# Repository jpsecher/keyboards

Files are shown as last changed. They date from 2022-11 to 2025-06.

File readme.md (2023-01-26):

# Custom Keyboard

Goals
- Good ergonomics
- Good for programming
- No drivers
- Configurable
- Use standard components where possible

On the ergonomics side, the initial design will be a pseudo-split staggered-column because it follows the natural physiology of the hands, and because I only need to make one or two for myself.  I want to make a PCB for the keyboard, so it seems to convoluted to go all the way to curved surfaces (eg. wells).  With a PCB, I can also support hot-swappable keys, which makes it possible to try out different spring weights for the individual fingers (like the [Absolem](https://zealot.hu/absolem/)).  And no stabilisers should be needed because the keys should just be where your finger naturally land, and therefore there should be no need for large 2U keys.  For the thumb keys, size 1.5U is probably sufficient.

Keys that need to be hold down while pressing other keys should only be operated by strong fingers.  So all modifier keys and layer shifting should probably be in the thumbs area, where it will be most comfortable to hold down a keys (as opposed to tapping the key).  But some modifier keys need to be hold down together, so these modifiers then need to be on opposite sides, using both thumbs at the same time.  

Good ergonomics with no curvatures then means that the number of keys must be limited to avoid stretching the fingers too much.  Which means that the keyboard needs to have several layers to accommodate all the ASCII characters used in programming, as well as the various European letters I use daily.  I am toying with the idea of using the thumb keys exclusively for layer-shift and control keys.

The keyboard should use standard hot-swappable Cherry MX keys.  And to ease experimentation, I will start out with DSA profile key caps.

## Layers

Contexts:

  1.  Programming (standard languages) in non-modal text editor.
  1.  Documentation (Markdown) in non-modal editor.
  1.  Terminal (shell) operations.
  1.  Window manager navigation.
  1.  Music control (easy identification of Play/Pause key at a glance)

And:

- Function keys are important in many of the applications I use.
- Editors usually inserts ending parenthesis/brace/bracket automatically.
- I don't care about RGB LEDs, as long as I can turn them off.
- I occasionally use Nordic/German/Greek letters when writing text.
- I want modifiers and layer keys on thumbs, and they should stay in the same place as much as possible.

Also, I prefer that each group of keys follow the traditional QWERTY layout, simply because it makes switching between keyboards less stressful.

## Keyboards in this repository

- [Acacia](acacia/): a pseudo-split 40 key column-staggered keyboard

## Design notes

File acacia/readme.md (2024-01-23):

# Acacia keyboard

A custom built mechanical keyboard with just 38 keys plus two extra media keys.

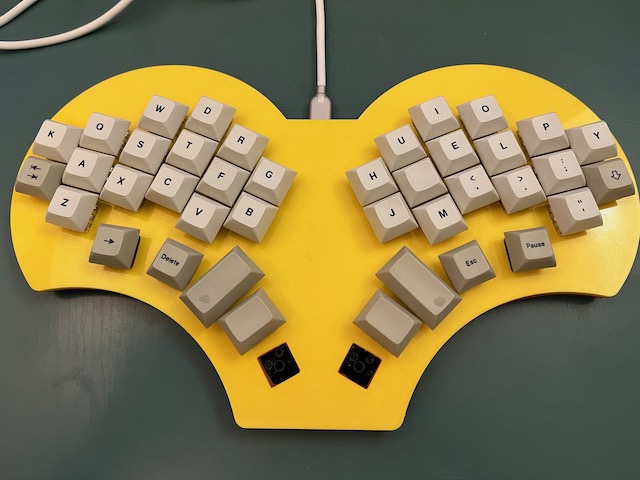
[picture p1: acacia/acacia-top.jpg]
Top side


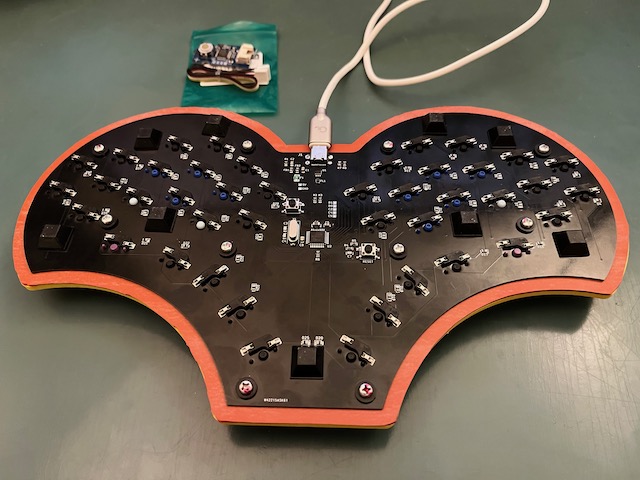
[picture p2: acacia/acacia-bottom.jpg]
PCB side


The [layout](acacia.pdf) uses three layers.  One for alphas, one for navigation/function keys, and one for symbols/numpad.

The thumb home keys double as layer switches and tab/space.  The lower thumb keys are one-shot shift keys.

The Escape key is a [Layer Lock](https://getreuer.info/posts/keyboards/layer-lock) on both upper layers, which eliminates the strain of holding down the thumb for prolonged navigation and number punching.  And it makes it possible to move one hand to a trackball while using the other hand for mouse buttons.

The lower home row (Z, X, C, V) doubles as modifiers (AltGr, GUI, Alt, Control), and these functions are mirrored on the other hand (M, comma, period, quote).  This mirroring of modifiers is carried through on both other layers.

If used on macOS, then the Control and GUI (Command) keys should be swapped at the OS level.

As seen on the picture, the current layout for the alphas is [Minimak-6](http://www.minimak.org/), and it works very well with the already relocated T and Y keys on Acacia.  It is pretty close to standard QWERTY, so changing between the two should not be a problem.

## Improvements

- Remove the now unused lower thumb keys.
- Adjust the thumb keys slightly to make sure that key caps of any reasonable size do not collide.  Also, the thumb home key could be a little less tilted, and the whole bock moved a little further towards the middle.
- Align Q and P keys with ring finger use (instead of pinky use), or simply tilt the pinky columns the same as the ring finger column.
- Include a trackball (as alluded to in the pictures).  Unfortunately the ATmega32U2 used in the build does not have built-in I2C communication, so unless the controller is upgraded to eg. ATmega32U4, the communication has to be done brute-force through some of the five unused GPIO pins.
- Make a proper (wooden?) case.
- Shielding for the PCB.
- Layer status output, eg. through LEDs.

## Alternatives

- After finishing the prototypes, I discovered this repo: https://github.com/AlaaSaadAbdo/battoota/

## Version 2

The TM040040 trackpad needs the R1 (470k) resistor removed to use I2C and the R7 (0?) & R8 (0?) resistors removed for 5V.  The flex cable needed is 05-12-D-0050-A or another cable with contacts on oposite sides.

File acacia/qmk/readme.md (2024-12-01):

# Acacia

A pseudo-split keyboard with 2+4x3+2 vertically staggered keys and 4+1 thumb keys for each hand.

* Keyboard Maintainer: [jpsecher](https://github.com/jpsecher)
* Hardware Supported: https://github.com/jpsecher/keyboards/acacia

Make example for this keyboard (after setting up your build environment):

    make handwired/acacia:default

Flashing example for this keyboard:

    make handwired/acacia:default:flash

See the [build environment setup](https://docs.qmk.fm/#/getting_started_build_tools) and the [make instructions](https://docs.qmk.fm/#/getting_started_make_guide) for more information.  If the chip is completely blank, then you might have to forcefully erase it like

    dfu-programmer atmega32u2 erase --force

## Acacia-2

    make handwired/acacia_2:qwerty-36-pc
    make handwired/acacia_2:qwerty-36-pc:flash

## Bootloader

Enter the bootloader by using the small buttons on the PCB: press the RESET button while connected to QMK Toolbox.

Then you can flash the HEX file you built above.

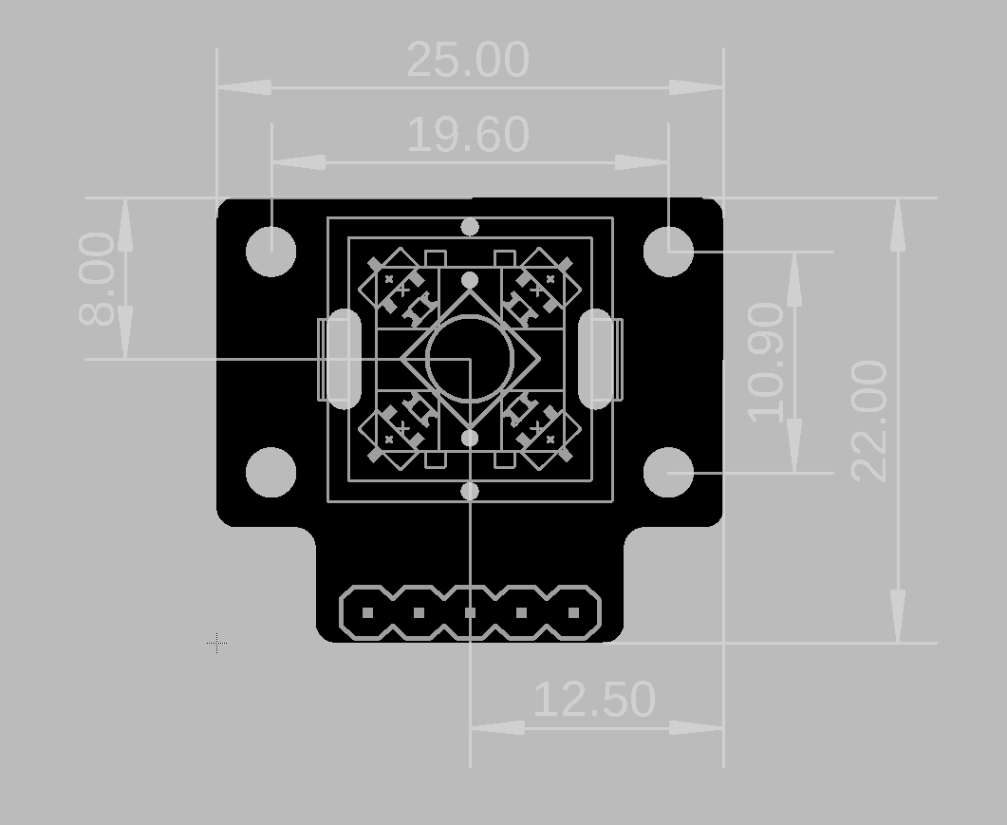
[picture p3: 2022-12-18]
doc/trackballbreakout.png

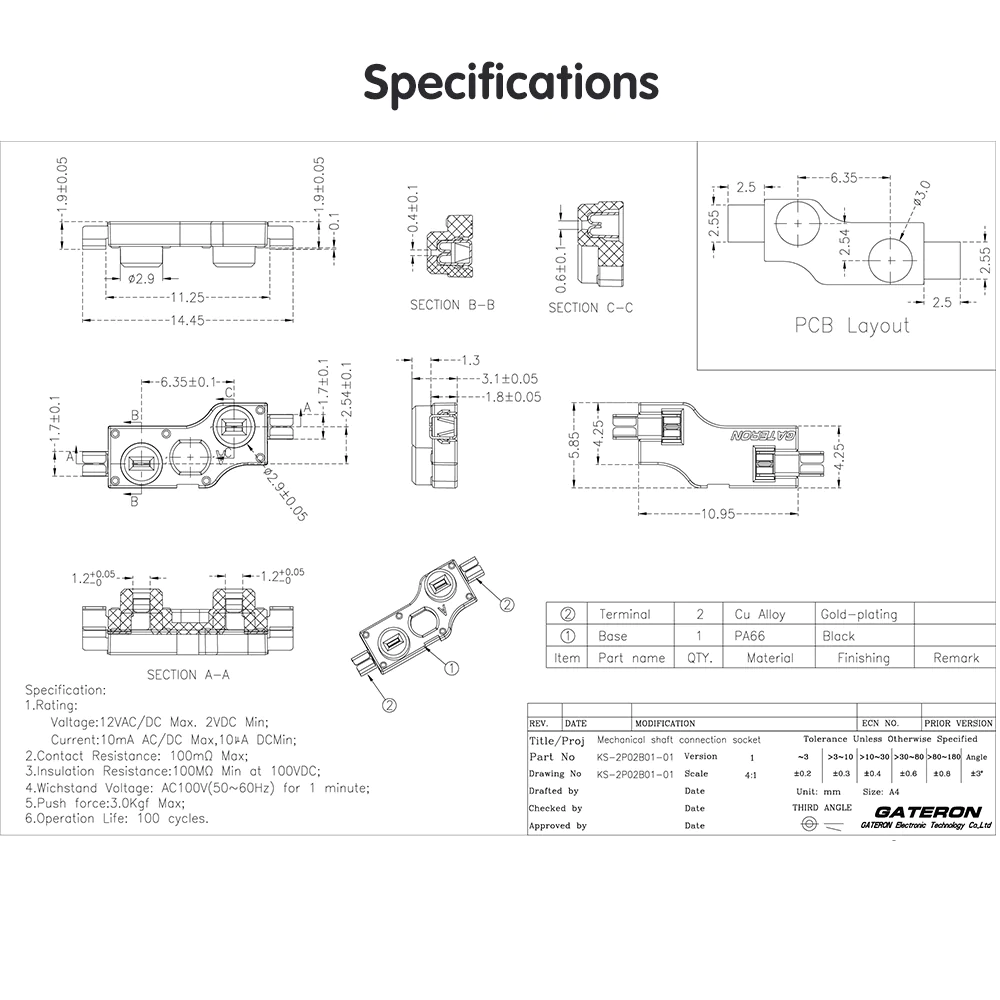
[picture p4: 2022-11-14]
doc/gateron.webp

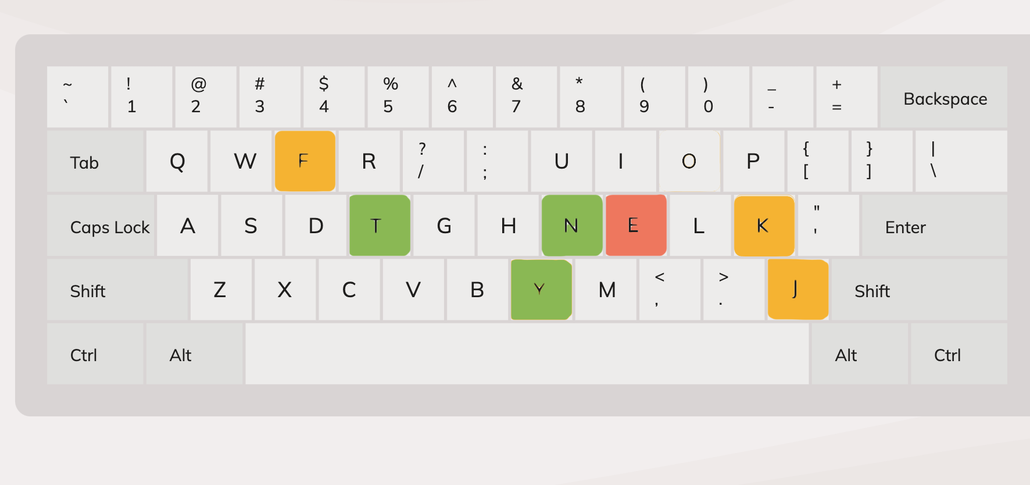
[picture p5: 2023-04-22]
acacia/acacia-diff-querty.png

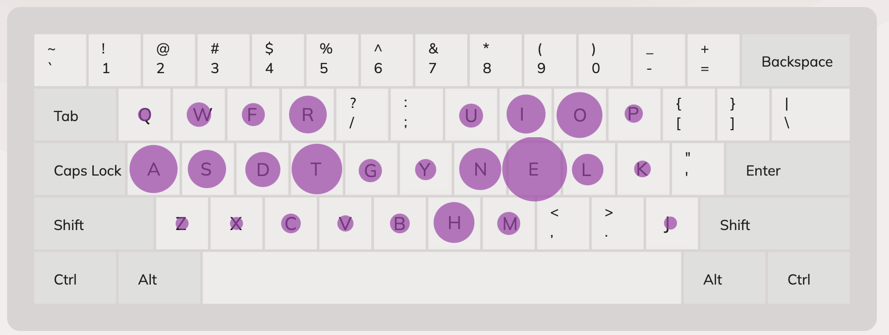
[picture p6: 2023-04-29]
acacia/acacia-on-us-keyboard.png

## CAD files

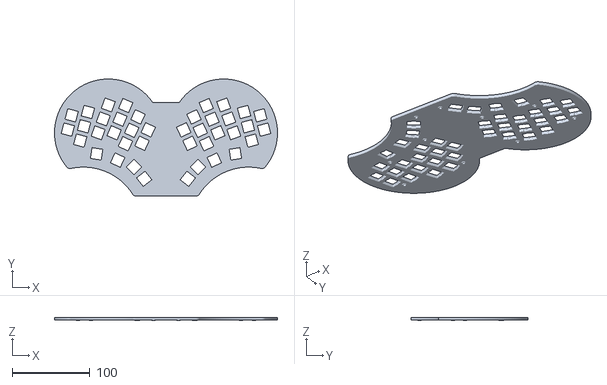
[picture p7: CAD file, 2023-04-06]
acacia/acacia.stl
286.0 x 150.0 x 4.40

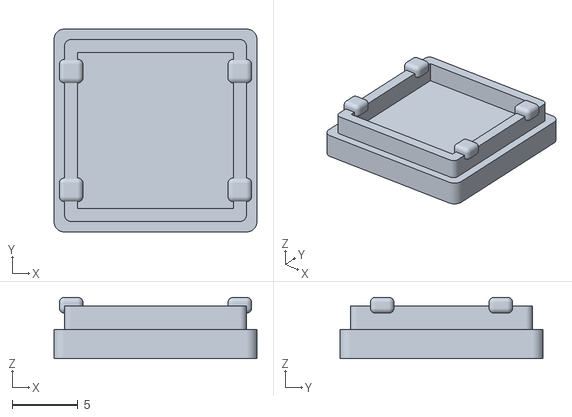
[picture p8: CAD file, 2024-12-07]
covers/choc-v1-cover.stl
15.4 x 15.4 x 4.65

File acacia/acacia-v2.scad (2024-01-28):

// Acacia V2
//
// A Mechanical Keyboard

$fn = 128;

// All constants are in mm
height = 4.6;
feet_height = 8;
wall = 4;
pcb_height = 1.2;
mountin_hole = 3;
membrane = 1;
key_distance = 19;
key_hole = 14;
key_tab_indent = 0.5;
key_tab_width = 5.0;
key_tab_submersion = 1.3;

module mirror2(vector) {
  children();
  mirror(vector) children();
}

module keyholder () {
  margin = 0.5;
  h = height+(2*margin);
  translate([0,0,-0.5]) {
    union() {
      // hole
      linear_extrude(h) {
        square(key_hole, center=true);
      }
      // botton indent for lock
      linear_extrude(h-margin-key_tab_submersion) {
        mirror2([0,1,0]) {
          translate([0,-(key_hole+key_tab_indent)/2,0]) {
            square([key_tab_width,key_tab_indent], center=true);
          }
        }
      }
    }
  }
}

module key (units) {
  union() {
    keyholder();
    // Outline of keycap, hidden by default
    *translate([0,0,height-1]) {
      linear_extrude(2) {
        square([key_distance*units-1,key_distance-1], center=true);
      }
    }
  }
}

module array (count, distance) {
  for (i=[0:1:count-1]) {
    translate([0,distance*i,0])
      children();
  }
}

module turn (degree) {
  rotate([0,0,degree])
    children();
}

module two_keys () {
  array(2, key_distance)
    key(1);
}

module three_keys () {
  array(3, key_distance)
    key(1);
}

module four_keys () {
  three_keys();
  translate([key_distance,key_distance,0]) turn(90) key(1.5);
}

module five_keys () {
  three_keys();
  translate([key_distance,key_distance/2,0]) two_keys();
}

module index_finger_full () {
  turn(15) mirror([1,0,0]) five_keys();
}

module middle_finger () {
  turn(15) three_keys();
}

module ring_finger () {
  turn(15) three_keys();
}

module pinky_full () {
  turn(15) four_keys();
}

module thumbs () {
  translate([71.7,80]) turn(-75) key(1.5);
  translate([50,68]) turn(15) key(1);
  translate([31.5,63]) turn(-75) key(1.5);
  translate([13,58]) turn(-75) key(1);
}

module right_hand () {
  translate([49,89,0]) index_finger_full();
  translate([65.5,103,0]) middle_finger();
  translate([86.5,99,0]) ring_finger();
  translate([108,93,0]) pinky_full();
  thumbs();
}

module plate_2d () {
  minkowski() {
    difference() {
      union() {
        translate([8,46,0]) square([100,82]);
        translate([82,104]) circle(50);
      }
      translate([98,-33,0]) circle(100);
    }
    circle(7);
  }
}

module interior_2d () {
  offset(-wall) plate_2d();
}

module interior_3d () {
  translate([0,0,-0.5]) {
    linear_extrude(feet_height+0.5) {
      interior_2d();
    }
  }
}

module plate_3d () {
  difference() {
    linear_extrude(height+feet_height) {
      plate_2d();
    }
    interior_3d();
  }
}

module right_side () {
  difference() {
    plate_3d();
    translate([3,-3,feet_height]) right_hand();
  }
}

module left_side () {
  mirror([1,0,0]) right_side();
}

// Complete 2D area without holes
module complete_2d () {
  difference () {
    union () {
      mirror2([1,0,0]) plate_2d();
      translate([0,87,0]) square([35,96], center=true);
    }
    *translate([0,133,0]) square([38,10], center=true);
    *translate([-18,150,0]) circle(22);
    *translate([18,150,0]) circle(22);
  }
}

*complete_2d();

module standoff () {
  difference() {
    translate([0,0,pcb_height]) {
      linear_extrude(membrane) circle(mountin_hole / 2 + 1);
    }
    translate([0,0,-1]) {
      linear_extrude(pcb_height + membrane + 2) 
        circle(mountin_hole / 2 - 0.1);
    }
  }
}

module standoffs_placement () {
  mirror2([1,0,0]) {
    translate([36,49,0]) children();
    translate([93,84,0]) children();
    translate([115,125,0]) children();
    translate([70,143,0]) children();
    translate([24,122,0]) children();
  }
}

module standoffs () {
  standoffs_placement() {
    standoff();
  }
}

module complete_interior_3d () {
  translate([0,0,-0.5]) {
    difference() {
      linear_extrude(feet_height+0.5+membrane) {
        offset(-wall) complete_2d();
      }
      translate([0,0,feet_height-0.5]) standoffs();
    }
  }
}

module complete_keyboard_3d () {
  difference() {
    linear_extrude(height+feet_height) {
      complete_2d();
    }
    complete_interior_3d();
  }
}

module keyboard () {
  difference () {
    complete_keyboard_3d();
    mirror2([1,0,0]) {
      translate([3,-3,feet_height]) right_hand();
    }
  }
}

*keyboard();

module holes () {
  standoffs_placement() {
    translate([0,0,-1]) {
      linear_extrude(height + membrane - 1) 
        circle(mountin_hole / 2 - 0.1);
    }    
  }
}

module plate () {
  difference() {
    union() {
      translate([0,0,membrane])
      difference() {
        linear_extrude(height-membrane) {
          complete_2d();
        }
        // cut out for flat cable
        translate([0,0,-1]) {
          linear_extrude(height-membrane + 2) {
            translate([0,65,0]) square([12,8], center=true);
          }
        }
        // cut out for USB plug
        translate([0,0,-2]) {
          linear_extrude(height-membrane) {
            translate([0,135,0]) square([15,10], center=true);
          }
        }
      }  
      translate([0,0,-membrane]) standoffs();
    }
    holes();
    mirror2([1,0,0]) {
      translate([3,-3,0]) right_hand();
    }
  }
}

// top plate for 3D printing
plate();

// trackpad
*translate([0,85,0]) circle(20);


module pcb () {
  linear_extrude(pcb_height) {
    difference() {
      offset(-wall-1) complete_2d();
      projection(cut=true) holes();
    }
  }
}

// guide for placing the switches & holes on the pcb
*projection() difference() {
  pcb();
  mirror2([1,0,0]) {
    translate([3,-3,-key_tab_submersion/2]) right_hand();
  }
}

// pcb outline
*projection() {
  linear_extrude(pcb_height) {
    offset(-wall-1) complete_2d();
  }
}

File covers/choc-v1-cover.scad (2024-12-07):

// Choc V2 Switch Hole Cover
// All measurements in millimeters
$fn = 128;

// Main Parameters
plate_thickness = 1.2;  // Thickness of the cover plate
plate_overhang = 2;
// tolerance = 0.2;    // Tolerance for better fit

switch_width = 13.8;  // Width of the switch cutout
lip_height = 0.4;
lip_width = 1;
lip_length = 10;

plate_width = switch_width + plate_overhang;

module lid_raw() {
    minkowski() {
        cube([switch_width, switch_width, plate_thickness]);
        cylinder(r=0.8,center=true);
    }
}
*lid_raw();

module lid() {
    translate([-switch_width / 2, -switch_width / 2, 0])
        lid_raw();
}

module rim_raw() {
    difference() {
        minkowski() {
            cube([switch_width - 1, switch_width - 1, 2]);
            cylinder(r=0.5,center=true);
        }
        translate([2*lip_width/2-0.5, 2*lip_width/2-0.5, 0])
            cube([switch_width - 2*lip_width, switch_width - 2*lip_width, 3]);
    }
}
*rim_raw();

module rim() {
    translate([-switch_width / 2 + 0.5, -switch_width / 2 + 0.5, 1])
        rim_raw();
}

module tap_raw() {
    union() {
        translate([0, 0, 1.65+0.5])
            minkowski() {
                cube([lip_width, lip_width, lip_height]);
                sphere(r=0.4);
            }
        translate([0, lip_length - lip_width, 1.65+0.5])
            minkowski() {
                cube([lip_width, lip_width, lip_height]);
                sphere(r=0.4);
            }
    }
}

module tap() {
    translate([-lip_width / 2, -lip_width / 2, plate_thickness])
        tap_raw();
}

module taps() {
    translate([(switch_width - lip_width)/2,-((lip_length-lip_width)/2),0])
        tap();
}

module switch_cover() {
    difference() {
        union() {
            lid();
            rim();
            taps();
            rotate([180,180,0]) taps();
        }
    }
}

switch_cover();

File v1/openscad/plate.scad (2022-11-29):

// The Pork Chop
//
// A Mechanical Keyboard

$fn = 128;

height = 5;
feet_height = 8;

key_distance = 19;

key_hole = 14;
key_tab_indent = 0.5;
key_tab_width = 5.0;
key_tab_submersion = 1.3;

module mirror2(vector) {
  children();
  mirror(vector) children();
}

module keyholder () {
  margin = 0.5;
  h = height+(2*margin);
  translate([0,0,-0.5]) {
    union() {
      // hole
      linear_extrude(h) {
        square(key_hole, center=true);
      }
      // botton indent
      linear_extrude(h-margin-key_tab_submersion) {
        mirror2([0,1,0]) {
          translate([0,-(key_hole+key_tab_indent)/2,0]) {
            square([key_tab_width,key_tab_indent], center=true);
          }
        }
      }
      // top indent
      *translate([0,0,margin+key_tab_submersion]) {
        linear_extrude(h-margin-key_tab_submersion) {
          mirror2([1,0,0]) {
            translate([-(key_hole+key_tab_indent)/2,0,0]) {
              square([key_tab_indent,key_tab_width], center=true);
            }
          }
        }
      }
    }
  }
}

module array (count, distance) {
  for (i=[0:1:count-1]) {
    translate([0,distance*i,0])
      children();
  }
}

module two_keys () {
  array(2, key_distance)
    keyholder();
}

module three_keys () {
  array(3, key_distance)
    keyholder();
}

module turn (degree) {
  rotate([0,0,degree])
    children();
}

module index_finger () {
  turn(25) three_keys();
}

module index_finger_extra () {
  turn(25) two_keys();
}

module middle_finger () {
  turn(23) three_keys();
}

module ring_finger () {
  turn(20) three_keys();
}

module pinkie () {
  turn(15) three_keys();
}

module pinkie_extra () {
  turn(15) two_keys();
}

module thumbs () {
  translate([59,69]) turn(38) keyholder();
  translate([41,55]) turn(55) keyholder();
  translate([30,33]) turn(70) keyholder();
  translate([26,8]) turn(85) keyholder();
}

module right_hand () {
  translate([28,89,0]) index_finger_extra();
  translate([49,90,0]) index_finger();
  translate([64,104,0]) middle_finger();
  translate([84,104,0]) ring_finger();
  translate([107,94,0]) pinkie();
  translate([123,109,0]) pinkie_extra();
  thumbs();
}

module plate_2d () {
  minkowski() {
    difference() {
      union() {
        translate([5,5,0]) square([120,105]);
        translate([72,107]) circle(67);
      }
      translate([140,0,0]) circle(90);
    }
    circle(5);
  }
}

module interior_2d () {
  offset(-5) plate_2d();
}

module interior_3d () {
  translate([0,0,-0.5]) {
    linear_extrude(feet_height+0.5) {
      interior_2d();
    }
  }
}

module plate_3d () {
  difference() {
    linear_extrude(height+feet_height) {
      plate_2d();
    }
    interior_3d();
  }
}

module right_side () {
  difference() {
    plate_3d();
    translate([0,7,feet_height]) right_hand();
  }
}

*right_side();

module left_side () {
  mirror([1,0,0]) right_side();
}

left_side();

module complete_2d () {
  mirror2([1,0,0]) plate_2d();
    difference () {
      translate([0,115,0]) square([15,40], center=true);
      translate([0,137,0]) circle(7);
    }
    translate([-5,0,0]) square(10);
}

module complete_interior_3d () {
  translate([0,0,-0.5]) {
    linear_extrude(feet_height+0.5) {
      offset(-5) complete_2d();
    }
  }
}

module complete_plate_3d () {
  difference() {
    linear_extrude(height+feet_height) {
      complete_2d();
    }
    complete_interior_3d();
  }
}

*difference () {
  complete_plate_3d();
  mirror2([1,0,0]) translate([-1,8,feet_height]) right_hand();
}

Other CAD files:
thrice/thrice.scad
acacia/acacia.scad

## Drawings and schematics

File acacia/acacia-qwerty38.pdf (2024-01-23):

## Keyboard handwired/acacia

## Layout LAYOUT

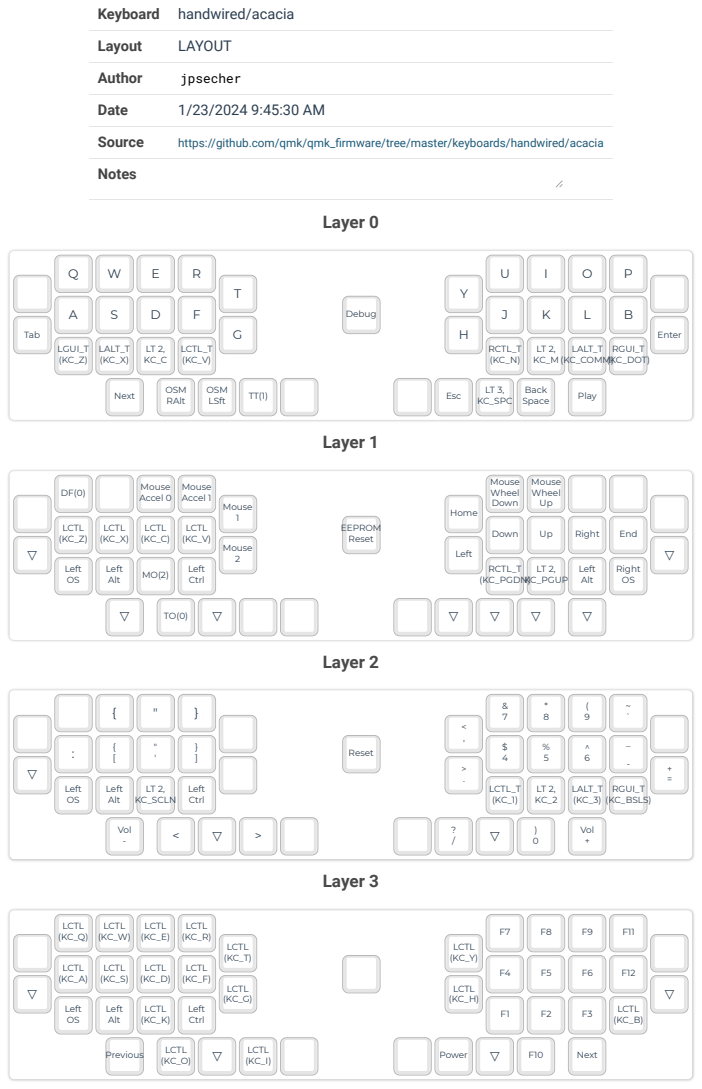
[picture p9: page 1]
Author; jpsecher; Date; Source; https://github.com/qmk/qmk_firmware/tree/master/keyboards/handwired/acacia; Notes; Layer 0; Layer 1; Layer 2; Layer 3; Tab; Enter; LGUI_T (KC_Z); LALT_T (KC_X); LCTL_T (KC_V); RCTL_T (KC_N); LALT_T (KC_COMM); RGUI_T (KC_DOT); Next; OSM; RAlt; OSM LSft; Esc; LT 3, KC_SPC; Back Space; Play; Debug; Mouse; Accel 0; Mouse Accel 1; Mouse 1; Home; Mouse Wheel; Down; LCTL (KC_Z); LCTL (KC_X); LCTL (KC_C); LCTL (KC_V); Mouse 2; Left; Right; End; Left OS; Alt; Left Ctrl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

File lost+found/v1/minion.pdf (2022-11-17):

## Keyboard handwired/pteron

## Layout LAYOUT

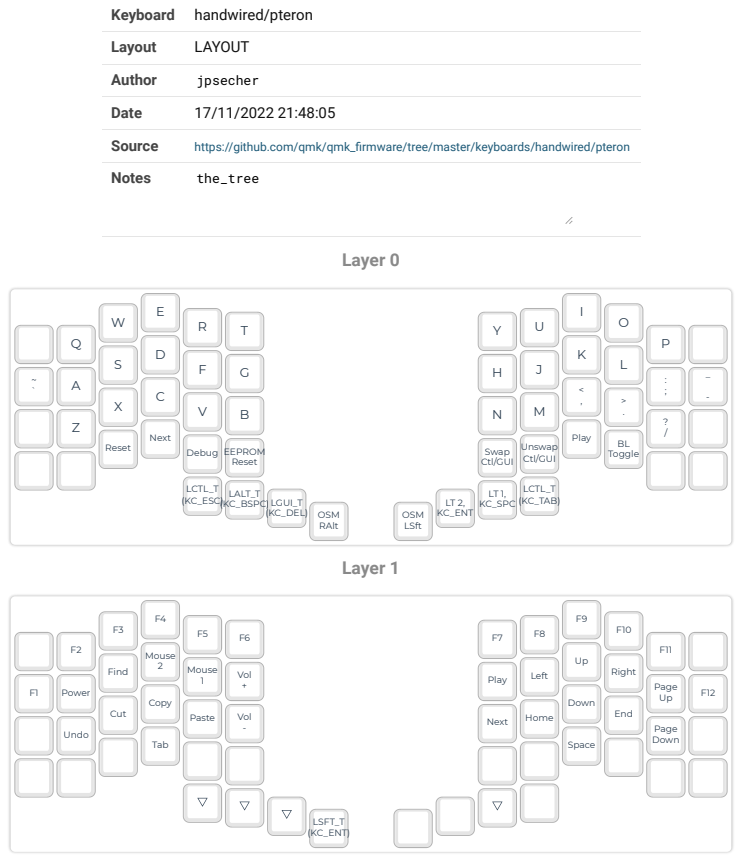
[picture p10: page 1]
Author; jpsecher; Date; Source; https://github.com/qmk/qmk_firmware/tree/master/keyboards/handwired/pteron; Notes; the_tree; Layer 0; Layer 1; Reset; Next; Debug; EEPROM; Swap Ctl/GUI; Unswap Ctl/GUI; Play; Toggle; LCTL_T (KC_ESC); LALT_T (KC_BSPC) LGUI_T; (KC_DEL); OSM; RAlt; OSM LSft; LT 2, KC_ENT; LT 1, KC_SPC; LCTL_T (KC_TAB); Power; Find; Mouse; Vol +; Left; Right; Page Up; Undo; Cut; Copy; Paste; Vol; Home; Down; End; Page Down; Tab; Space; LSFT_T; (KC_ENT)

L

a

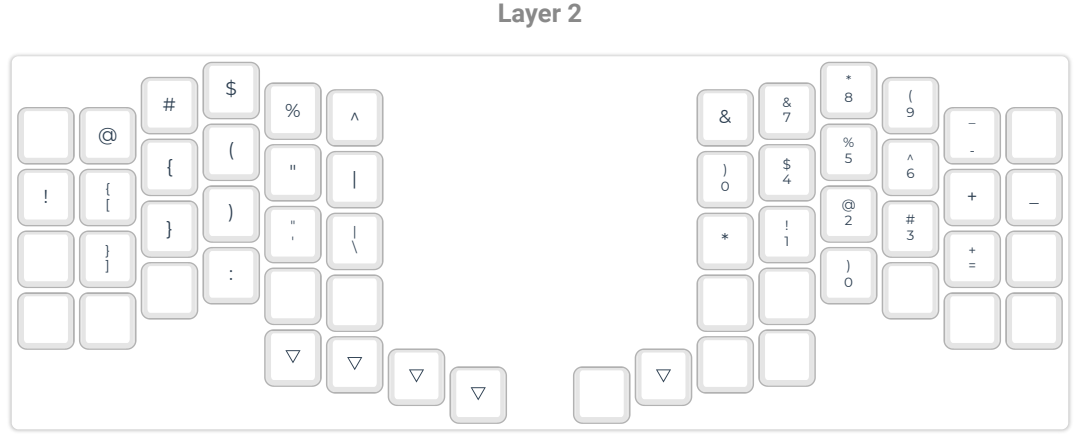
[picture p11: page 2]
yer

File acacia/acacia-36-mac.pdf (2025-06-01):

# Layer 0

Q | W | E | R

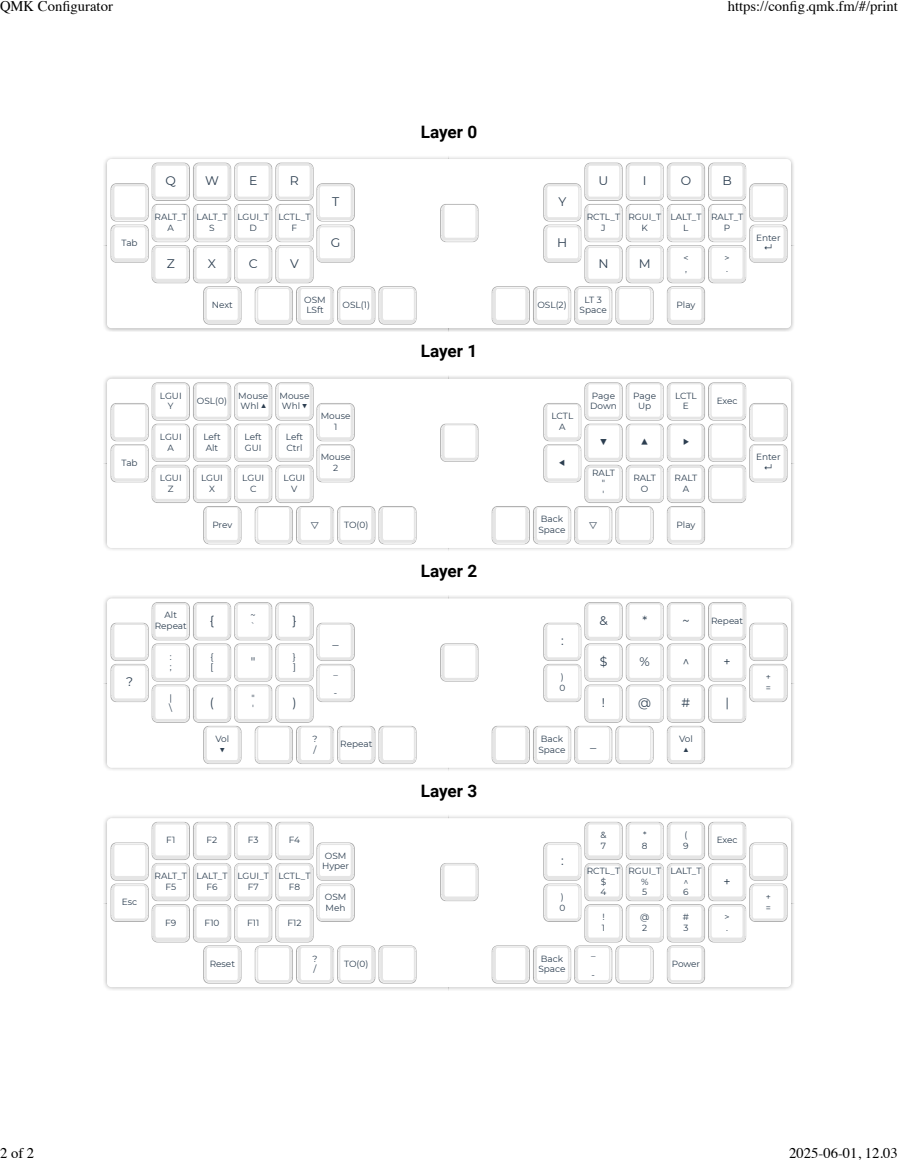
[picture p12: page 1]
Layer 1; Layer 2; Layer 3; Tab; RALT_T A; LALT_T S; LGUI_T D; LCTL_T F; RCTL_T J; RGUI_T K; LALT_T L; RALT_T P; Enter ↵; Next; OSM; LSft; OSL(1); OSL(2); Space; Play; LGUI; OSL(0); Mouse; Whl ⏶; Mouse Whl ⏷; Mouse 1; LCTL A; Page Down; Page Up; LCTL; Exec; LGUI A; Left Alt; Left GUI; Left Ctrl; LGUI Z; LGUI X; LGUI C; LGUI V; RALT " '; RALT O; RALT A; Prev; Back; Alt; Repeat; Vol ⏷; Vol; Hyper; Esc; RALT_T F5; LALT_T F6; LGUI_T F7; LCTL_T F8; OSM Meh; RCTL_T $ 4; RGUI_T % 5; LALT_T ^ 6; Reset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

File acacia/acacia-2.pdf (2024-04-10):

## Keyboard handwired/acacia

## Layout LAYOUT

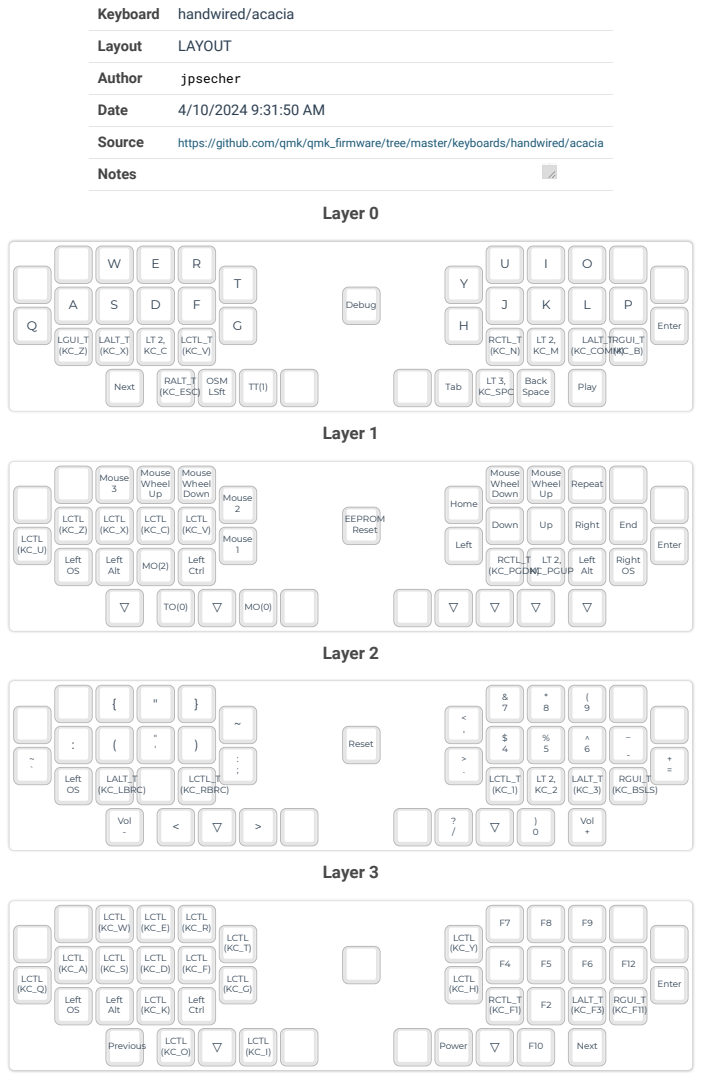
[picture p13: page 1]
Author; jpsecher; Date; Source; https://github.com/qmk/qmk_firmware/tree/master/keyboards/handwired/acacia; Notes; Layer 0; Layer 1; Layer 2; Layer 3; Enter; LGUI_T (KC_Z); LALT_T (KC_X); LCTL_T (KC_V); RCTL_T (KC_N); LALT_T (KC_COMM); RGUI_T (KC_B); Next; RALT_T (KC_ESC); OSM LSft; Tab; LT 3, KC_SPC; Back Space; Play; Debug; Mouse 3; Mouse Wheel; Down; Mouse; Home; Repeat; LCTL (KC_U); LCTL (KC_Z); LCTL (KC_X); LCTL (KC_C); LCTL (KC_V); Mouse 1; Left; Right; End; Left OS; Alt; Left Ctrl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

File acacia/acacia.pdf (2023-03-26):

## Keyboard handwired/acacia

## Layout LAYOUT

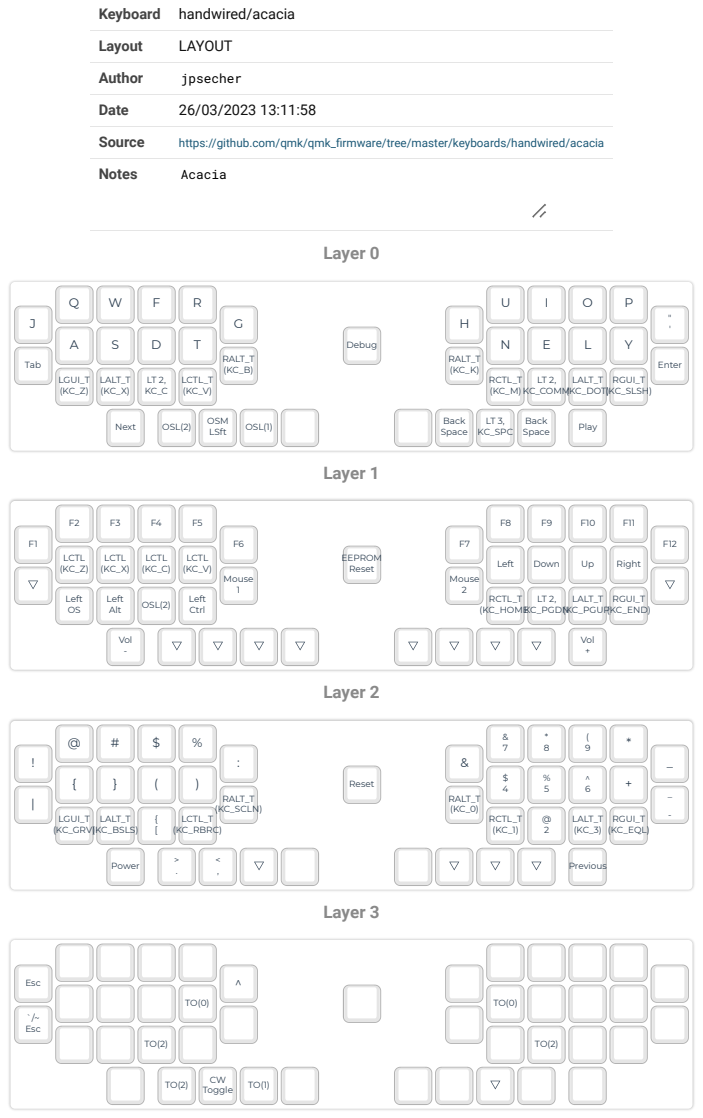
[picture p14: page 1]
Author; jpsecher; Date; Source; https://github.com/qmk/qmk_firmware/tree/master/keyboards/handwired/acacia; Notes; Acacia; Layer 0; Layer 1; Layer 2; Layer 3; Tab; RALT_T (KC_B); RALT_T (KC_K); Enter; LGUI_T (KC_Z); LALT_T (KC_X); LCTL_T (KC_V); RCTL_T (KC_M); LT 2, KC_COMM; LALT_T (KC_DOT); RGUI_T (KC_SLSH); Next; OSL(2); OSM; LSft; OSL(1); Back Space; LT 3, KC_SPC; Play; Debug; LCTL (KC_Z); LCTL (KC_X); LCTL (KC_C); LCTL (KC_V); Mouse 1; Mouse 2; Left; Down; Right; Left OS; Alt; Left Ctrl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

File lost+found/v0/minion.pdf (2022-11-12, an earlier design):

## Keyboard dailycraft/claw44/rev1

## Layout LAYOUT

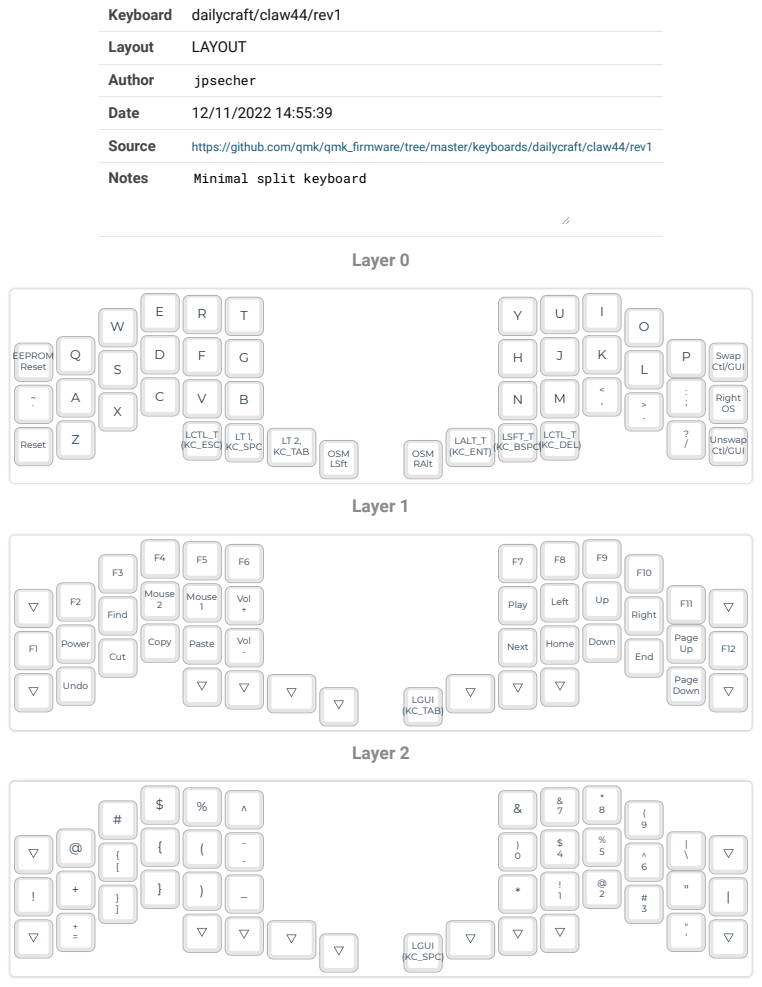
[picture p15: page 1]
Author; jpsecher; Date; Source; https://github.com/qmk/qmk_firmware/tree/master/keyboards/dailycraft/claw44/rev1; Notes; Minimal split keyboard; Layer 0; Layer 1; Layer 2; EEPROM Reset; Swap; Ctl/GUI; Right; Reset; Unswap; LCTL_T (KC_ESC); LT 1, KC_SPC; KC_TAB; OSM; LSft; OSM RAlt; LALT_T (KC_ENT); LSFT_T (KC_BSPC); LCTL_T (KC_DEL); Power; Find; Mouse 2; Mouse 1; Vol +; Play; Left; Page; Undo; Cut; Copy; Paste; Vol; Next; Home; Down; End; Page ▽; LGUI (KC_TAB); LGUI (KC_SPC)

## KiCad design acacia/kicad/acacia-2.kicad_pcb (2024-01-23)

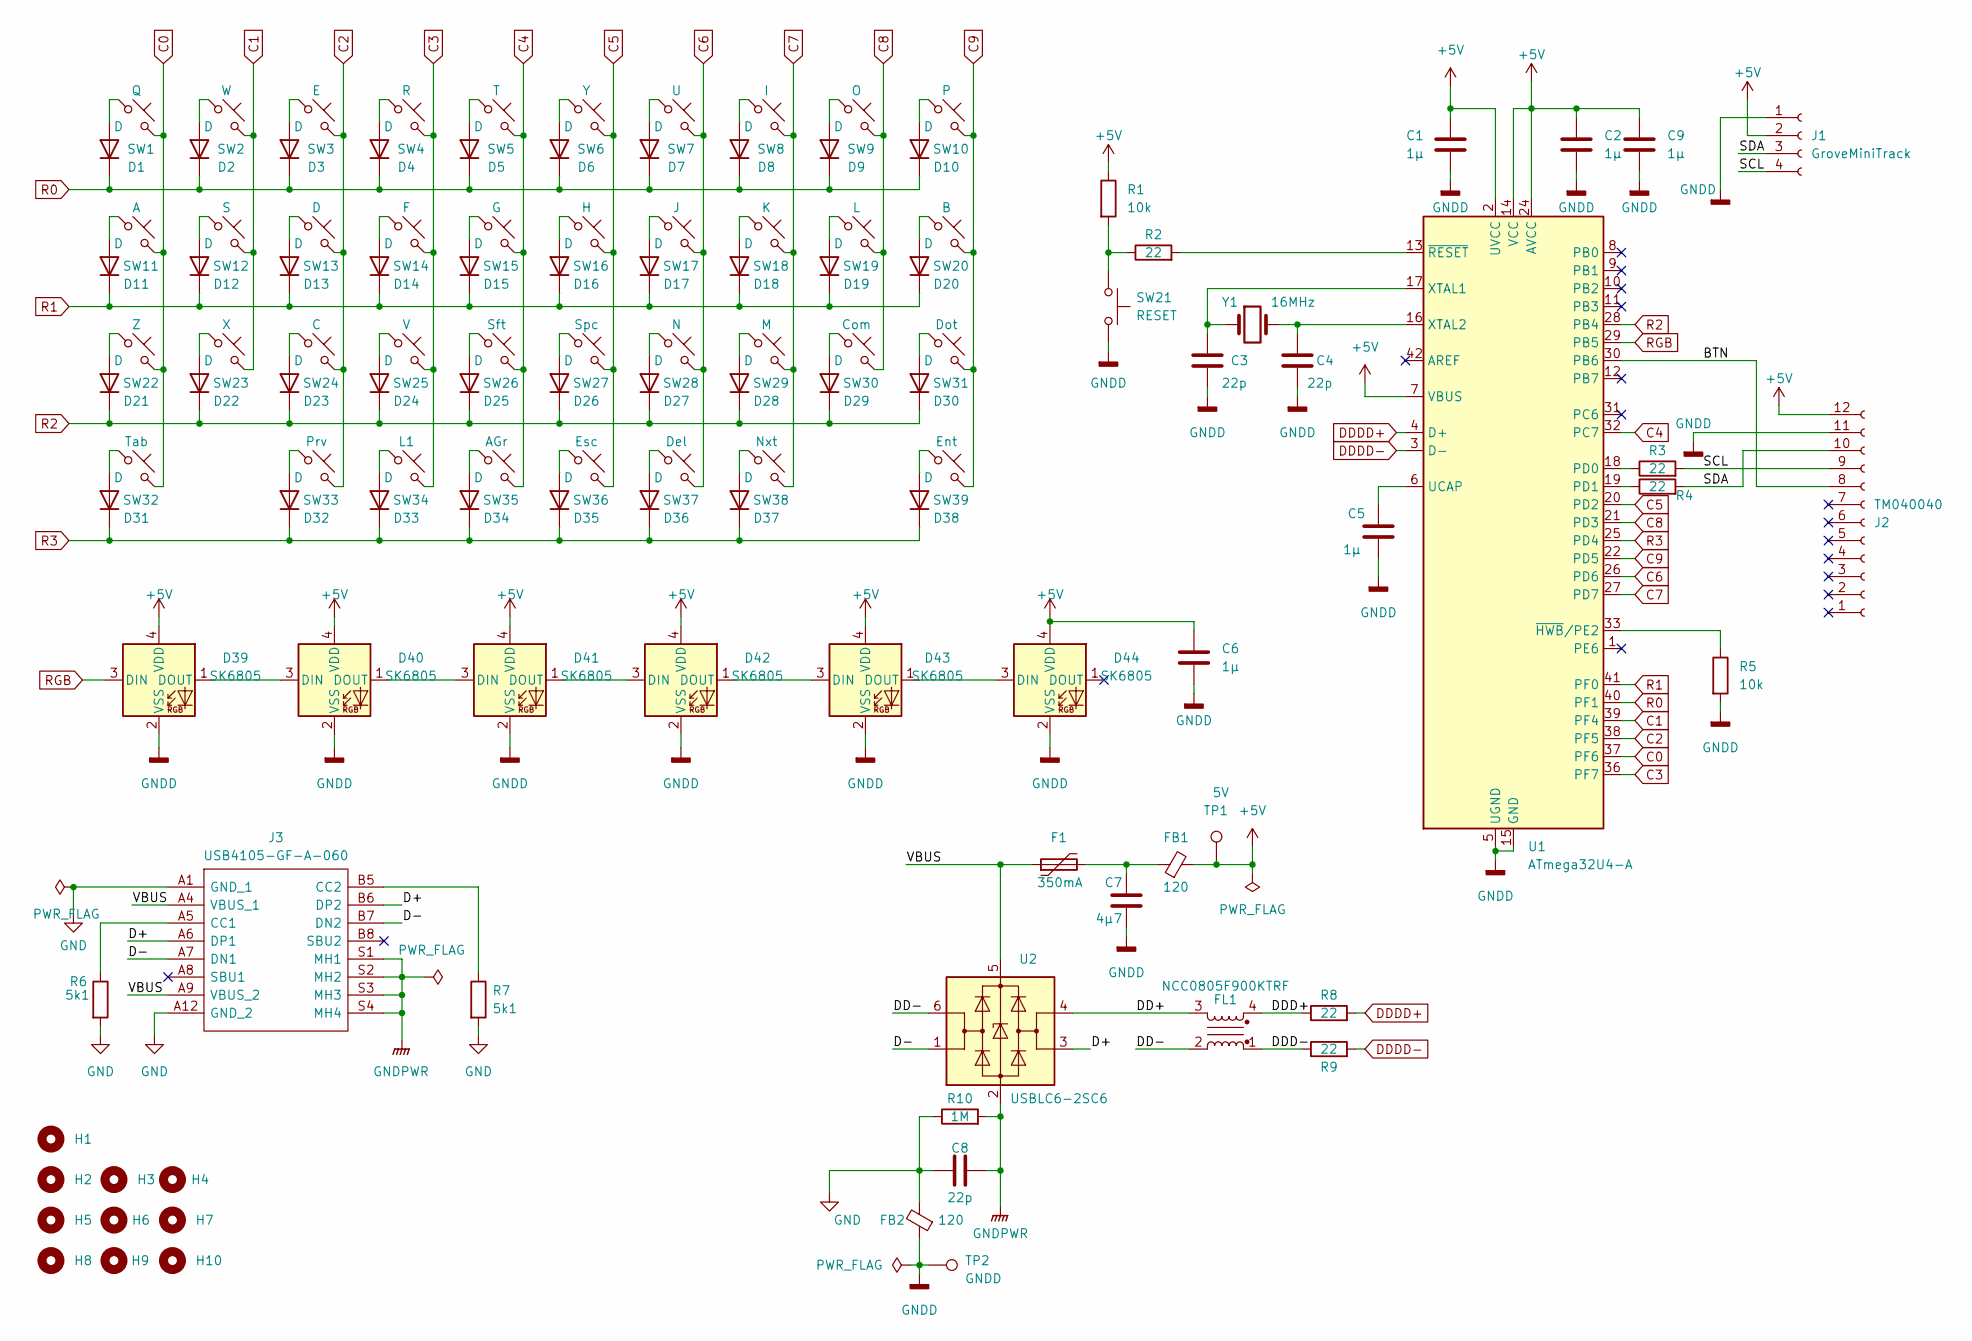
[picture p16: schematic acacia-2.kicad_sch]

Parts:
C1: 1µ; C_1206_3216Metric_Pad1.33x1.80mm_HandSolder
C2, C5, C6, C9: 1µ; C_0805_2012Metric_Pad1.18x1.45mm_HandSolder
C3, C4, C8: 22p; C_0805_2012Metric_Pad1.18x1.45mm_HandSolder
C7: 4µ7; C_0805_2012Metric_Pad1.18x1.45mm_HandSolder
D1, D2, D3, D4, D5, D6, D7, D8, D9, D10, D11, D12, D13, D14, D15, D16, D17, D18, D19, D20, D21, D22, D23, D24, D25, D26, D27, D28, D29, D30, D31, D32, D33, D34, D35, D36, D37, D38: D; D_0805_2012Metric_Pad1.15x1.40mm_HandSolder
D39, D40, D41, D42, D43, D44: SK6805; LED_SK6812_EC15_1.5x1.5mm
F1: 350mA; R_1206_3216Metric_Pad1.30x1.75mm_HandSolder
FB1, FB2: 120; R_0805_2012Metric_Pad1.20x1.40mm_HandSolder
FL1: NCC0805F900KTRF; L_CommonModeChoke_Coilcraft_0805USB
H1, H2, H3, H4, H5, H6, H7, H8, H9, H10: MountingHole; MountingHole_3.2mm_M3
J1: GroveMiniTrack; JST_XA_B04B-XASK-1-A_1x04_P2.50mm_Vertical
J2: TM040040; Hirose_FH12-12S-0.5SH_1x12-1MP_P0.50mm_Horizontal
J3: USB4105-GF-A-060; GCT_USB4105-GF-A; Mouser Part Number 640-USB4500030A
R1, R5: 10k; R_0805_2012Metric_Pad1.20x1.40mm_HandSolder
R2, R3, R4, R8, R9: 22; R_0805_2012Metric_Pad1.20x1.40mm_HandSolder
R6, R7: 5k1; R_0805_2012Metric_Pad1.20x1.40mm_HandSolder
R10: 1M; R_0805_2012Metric_Pad1.20x1.40mm_HandSolder
SW1: Q; MX-Hotswap-1U
SW2: W; MX-Hotswap-1U
SW3: E; MX-Hotswap-1U
SW4: R; MX-Hotswap-1U
SW5: T; MX-Hotswap-1U
SW6: Y; MX-Hotswap-1U
SW7: U; MX-Hotswap-1U
SW8: I; MX-Hotswap-1U
SW9: O; MX-Hotswap-1U
SW10: P; MX-Hotswap-1U
SW11: A; MX-Hotswap-1U
SW12: S; MX-Hotswap-1U
SW13: D; MX-Hotswap-1U
SW14: F; MX-Hotswap-1U
SW15: G; MX-Hotswap-1U
SW16: H; MX-Hotswap-1U
SW17: J; MX-Hotswap-1U
SW18: K; MX-Hotswap-1U
SW19: L; MX-Hotswap-1U
SW20: B; MX-Hotswap-1U
SW21: RESET; SW_SPST_EVQQ2
SW22: Z; MX-Hotswap-1U
SW23: X; MX-Hotswap-1U
SW24: C; MX-Hotswap-1U
SW25: V; MX-Hotswap-1U
SW26: Sft; MX-Hotswap-1.5U
SW27: Spc; MX-Hotswap-1.5U
SW28: N; MX-Hotswap-1U
SW29: M; MX-Hotswap-1U
SW30: Com; MX-Hotswap-1U
SW31: Dot; MX-Hotswap-1U
SW32: Tab; MX-Hotswap-1.5U
SW33: Prv; MX-Hotswap-1.5U
SW34: L1; MX-Hotswap-1U
SW35: AGr; MX-Hotswap-1.5U
SW36: Esc; MX-Hotswap-1.5U
SW37: Del; MX-Hotswap-1U
SW38: Nxt; MX-Hotswap-1.5U
SW39: Ent; MX-Hotswap-1.5U
TP1: 5V; TestPoint_Pad_D1.5mm
TP2: GNDD; TestPoint_Pad_D1.5mm
U1: ATmega32U4-A; TQFP-44_10x10mm_P0.8mm
U2: USBLC6-2SC6; SOT-23-6
Y1: 16MHz; Crystal_SMD_HC49-SD

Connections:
+5V: C1.1, C2.1, C6.1, C9.1, D39.4 (VDD), D40.4 (VDD), D41.4 (VDD), D42.4 (VDD), D43.4 (VDD), D44.4 (VDD), FB1.2, J1.2, J2.12, R1.1, TP1.1, U1.2 (UVCC), U1.7 (VBUS), U1.14 (VCC), U1.24 (AVCC), U1.34 (VCC), U1.44 (AVCC)
/BTN: J2.8, U1.30 (PB6)
/D+: J3.A6 (DP1), J3.B6 (DP2), U2.3 (I/O2)
/D-: J3.A7 (DN1), J3.B7 (DN2), U2.1 (I/O1)
/DD+: FL1.3, U2.4 (I/O2)
/DD-: FL1.2, U2.6 (I/O1)
/DDD+: FL1.4, R8.1
/DDD-: FL1.1, R9.1
/SCL: J1.4, J2.9, R3.2
/SDA: J1.3, J2.10, R4.2
/VBUS: F1.1, J3.A4 (VBUS_1), J3.A9 (VBUS_2), U2.5 (VBUS)
C0: SW1.2, SW11.2, SW22.2, SW32.2, U1.37 (PF6)
C1: SW2.2, SW12.2, SW23.2, U1.39 (PF4)
C2: SW3.2, SW13.2, SW24.2, SW33.2, U1.38 (PF5)
C3: SW4.2, SW14.2, SW25.2, SW34.2, U1.36 (PF7)
C4: SW5.2, SW15.2, SW26.2, SW35.2, U1.32 (PC7)
C5: SW6.2, SW16.2, SW27.2, SW36.2, U1.20 (PD2)
C6: SW7.2, SW17.2, SW28.2, SW37.2, U1.26 (PD6)
C7: SW8.2, SW18.2, SW29.2, SW38.2, U1.27 (PD7)
C8: SW9.2, SW19.2, SW30.2, U1.21 (PD3)
C9: SW10.2, SW20.2, SW31.2, SW39.2, U1.22 (PD5)
DDDD+: R8.2, U1.4 (D+)
DDDD-: R9.2, U1.3 (D-)
GND: C8.1, FB2.2, J3.A1 (GND_1), J3.A12 (GND_2), R6.2, R7.2, R10.1
GNDD: C1.2, C2.2, C3.2, C4.2, C5.2, C6.2, C7.1, C9.2, D39.2 (VSS), D40.2 (VSS), D41.2 (VSS), D42.2 (VSS), D43.2 (VSS), D44.2 (VSS), FB2.1, J1.1, J2.11, R5.2, SW21.2, TP2.1, U1.5 (UGND), U1.15 (GND), U1.23 (GND), U1.35 (GND), U1.43 (GND)
GNDPWR: C8.2, J3.S1 (MH1), J3.S2 (MH2), J3.S3 (MH3), J3.S4 (MH4), R10.2, U2.2 (GND)
unnamed: C7.2, F1.2, FB1.1
unnamed: D1.2 (A), SW1.1
unnamed: D2.2 (A), SW2.1
unnamed: D3.2 (A), SW3.1
unnamed: D4.2 (A), SW4.1
unnamed: D5.2 (A), SW5.1
unnamed: D6.2 (A), SW6.1
unnamed: D7.2 (A), SW7.1
unnamed: D8.2 (A), SW8.1
unnamed: D9.2 (A), SW9.1
unnamed: D10.2 (A), SW10.1
unnamed: D11.2 (A), SW11.1
unnamed: D12.2 (A), SW12.1
unnamed: D13.2 (A), SW13.1
unnamed: D14.2 (A), SW14.1
unnamed: D15.2 (A), SW15.1
unnamed: D16.2 (A), SW16.1
unnamed: D17.2 (A), SW17.1
unnamed: D18.2 (A), SW18.1
unnamed: D19.2 (A), SW19.1
unnamed: D20.2 (A), SW20.1
unnamed: D21.2 (A), SW22.1
unnamed: D22.2 (A), SW23.1
unnamed: D23.2 (A), SW24.1
unnamed: D24.2 (A), SW25.1
unnamed: D25.2 (A), SW26.1
unnamed: D26.2 (A), SW27.1
unnamed: D27.2 (A), SW28.1
unnamed: D28.2 (A), SW29.1
unnamed: D29.2 (A), SW30.1
unnamed: D30.2 (A), SW31.1
unnamed: D31.2 (A), SW32.1
unnamed: D32.2 (A), SW33.1
unnamed: D33.2 (A), SW34.1
unnamed: D34.2 (A), SW35.1
unnamed: D35.2 (A), SW36.1
unnamed: D36.2 (A), SW37.1
unnamed: D37.2 (A), SW38.1
unnamed: D38.2 (A), SW39.1
unnamed: D39.1 (DOUT), D40.3 (DIN)
unnamed: D40.1 (DOUT), D41.3 (DIN)
unnamed: D41.1 (DOUT), D42.3 (DIN)
unnamed: D42.1 (DOUT), D43.3 (DIN)
unnamed: D43.1 (DOUT), D44.3 (DIN)
unnamed: J3.A5 (CC1), R6.1
unnamed: J3.B5 (CC2), R7.1
unnamed: R1.2, R2.1, SW21.1
unnamed: R3.1, U1.18 (PD0)
unnamed: R4.1, U1.19 (PD1)
unnamed: C5.1, U1.6 (UCAP)
unnamed: C3.1, U1.17 (XTAL1), Y1.1
unnamed: C4.1, U1.16 (XTAL2), Y1.2
unnamed: R5.1, U1.33 (~HWB/PE2)
unnamed: R2.2, U1.13 (~RESET)
R0: D1.1 (K), D2.1 (K), D3.1 (K), D4.1 (K), D5.1 (K), D6.1 (K), D7.1 (K), D8.1 (K), D9.1 (K), D10.1 (K), U1.40 (PF1)
R1: D11.1 (K), D12.1 (K), D13.1 (K), D14.1 (K), D15.1 (K), D16.1 (K), D17.1 (K), D18.1 (K), D19.1 (K), D20.1 (K), U1.41 (PF0)
R2: D21.1 (K), D22.1 (K), D23.1 (K), D24.1 (K), D25.1 (K), D26.1 (K), D27.1 (K), D28.1 (K), D29.1 (K), D30.1 (K), U1.28 (PB4)
R3: D31.1 (K), D32.1 (K), D33.1 (K), D34.1 (K), D35.1 (K), D36.1 (K), D37.1 (K), D38.1 (K), U1.25 (PD4)
RGB: D39.3 (DIN), U1.29 (PB5)

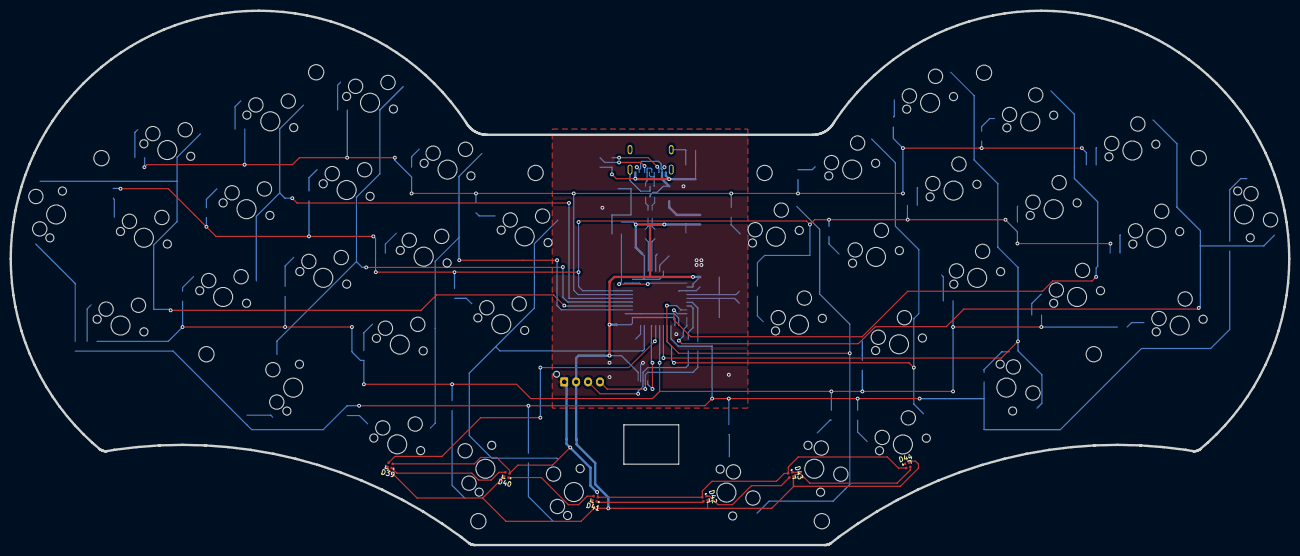
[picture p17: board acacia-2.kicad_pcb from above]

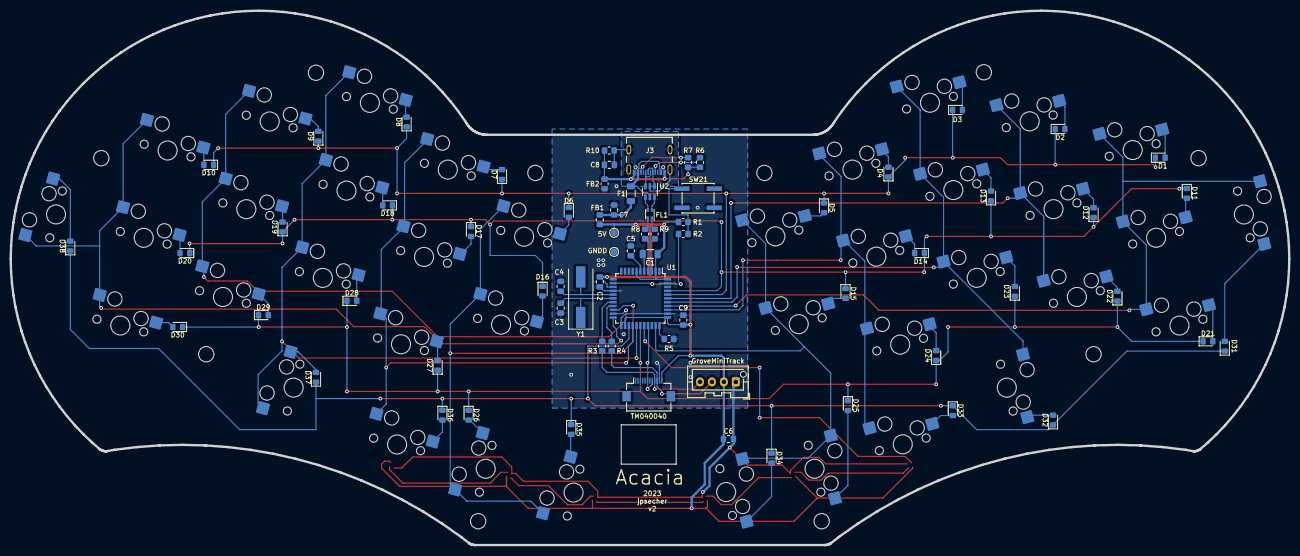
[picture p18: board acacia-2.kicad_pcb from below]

Board: 2 copper layers, 268.0 x 112.0 mm, 124 parts (80 on the bottom side), 85 nets.

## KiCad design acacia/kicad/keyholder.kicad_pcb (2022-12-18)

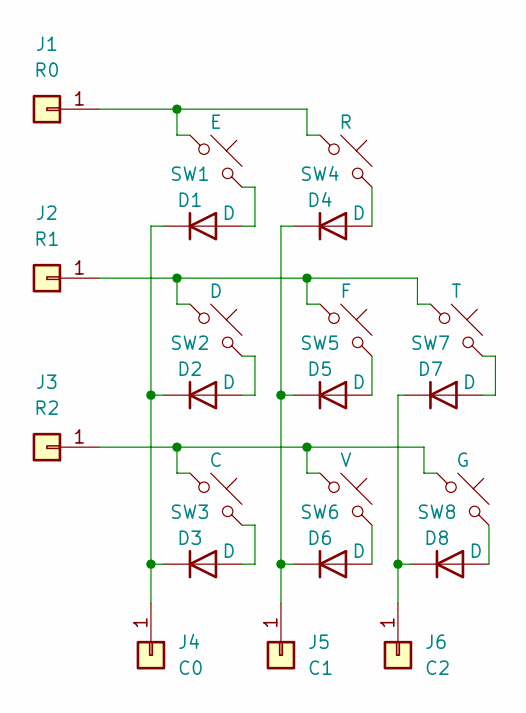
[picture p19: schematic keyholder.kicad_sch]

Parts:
D1, D2, D3, D4, D5, D6, D7, D8: D; D_0805_2012Metric_Pad1.15x1.40mm_HandSolder
J1: R0; Pin_D0.7mm_L6.5mm_W1.8mm_FlatFork
J2: R1; Pin_D0.7mm_L6.5mm_W1.8mm_FlatFork
J3: R2; Pin_D0.7mm_L6.5mm_W1.8mm_FlatFork
J4: C0; Pin_D0.7mm_L6.5mm_W1.8mm_FlatFork
J5: C1; Pin_D0.7mm_L6.5mm_W1.8mm_FlatFork
J6: C2; Pin_D0.7mm_L6.5mm_W1.8mm_FlatFork
SW1: E; MX-Hotswap-1U
SW2: D; MX-Hotswap-1U
SW3: C; MX-Hotswap-1U
SW4: R; MX-Hotswap-1U
SW5: F; MX-Hotswap-1U
SW6: V; MX-Hotswap-1U
SW7: T; MX-Hotswap-1U
SW8: G; MX-Hotswap-1U

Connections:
unnamed: D1.1 (K), D2.1 (K), D3.1 (K), J4.1
unnamed: D1.2 (A), SW1.2
unnamed: D2.2 (A), SW2.2
unnamed: D3.2 (A), SW3.2
unnamed: D4.1 (K), D5.1 (K), D6.1 (K), J5.1
unnamed: D4.2 (A), SW4.2
unnamed: D5.2 (A), SW5.2
unnamed: D6.2 (A), SW6.2
unnamed: D7.1 (K), D8.1 (K), J6.1
unnamed: D7.2 (A), SW7.2
unnamed: D8.2 (A), SW8.2
unnamed: J1.1, SW1.1, SW4.1
unnamed: J2.1, SW2.1, SW5.1, SW7.1
unnamed: J3.1, SW3.1, SW6.1, SW8.1

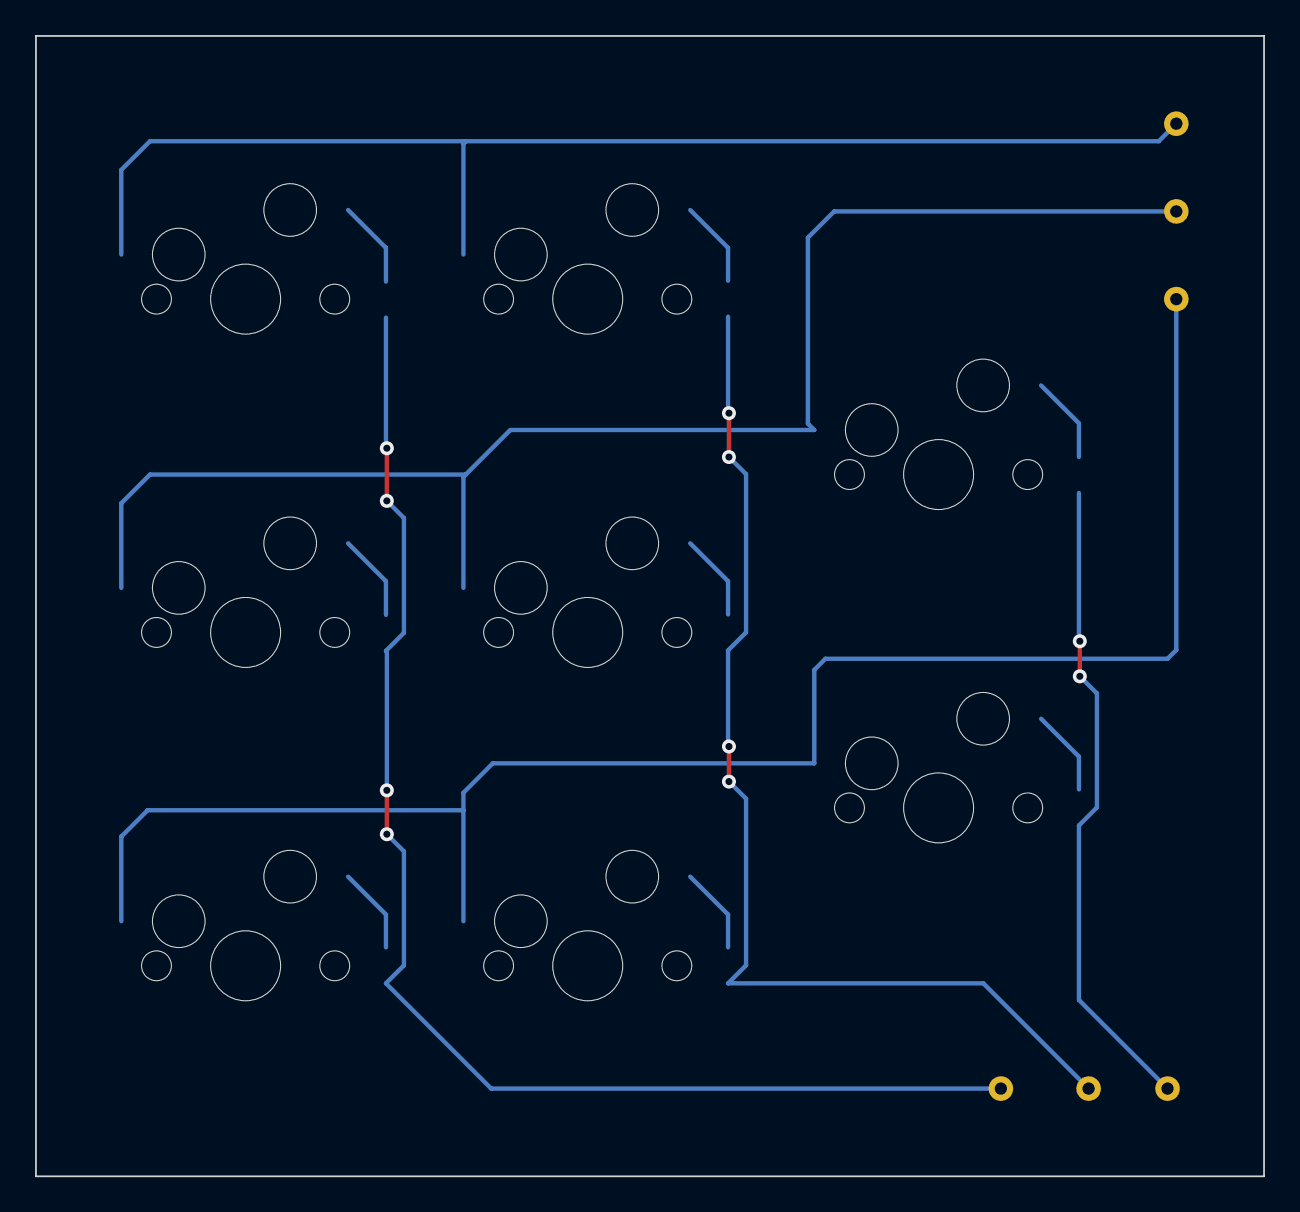
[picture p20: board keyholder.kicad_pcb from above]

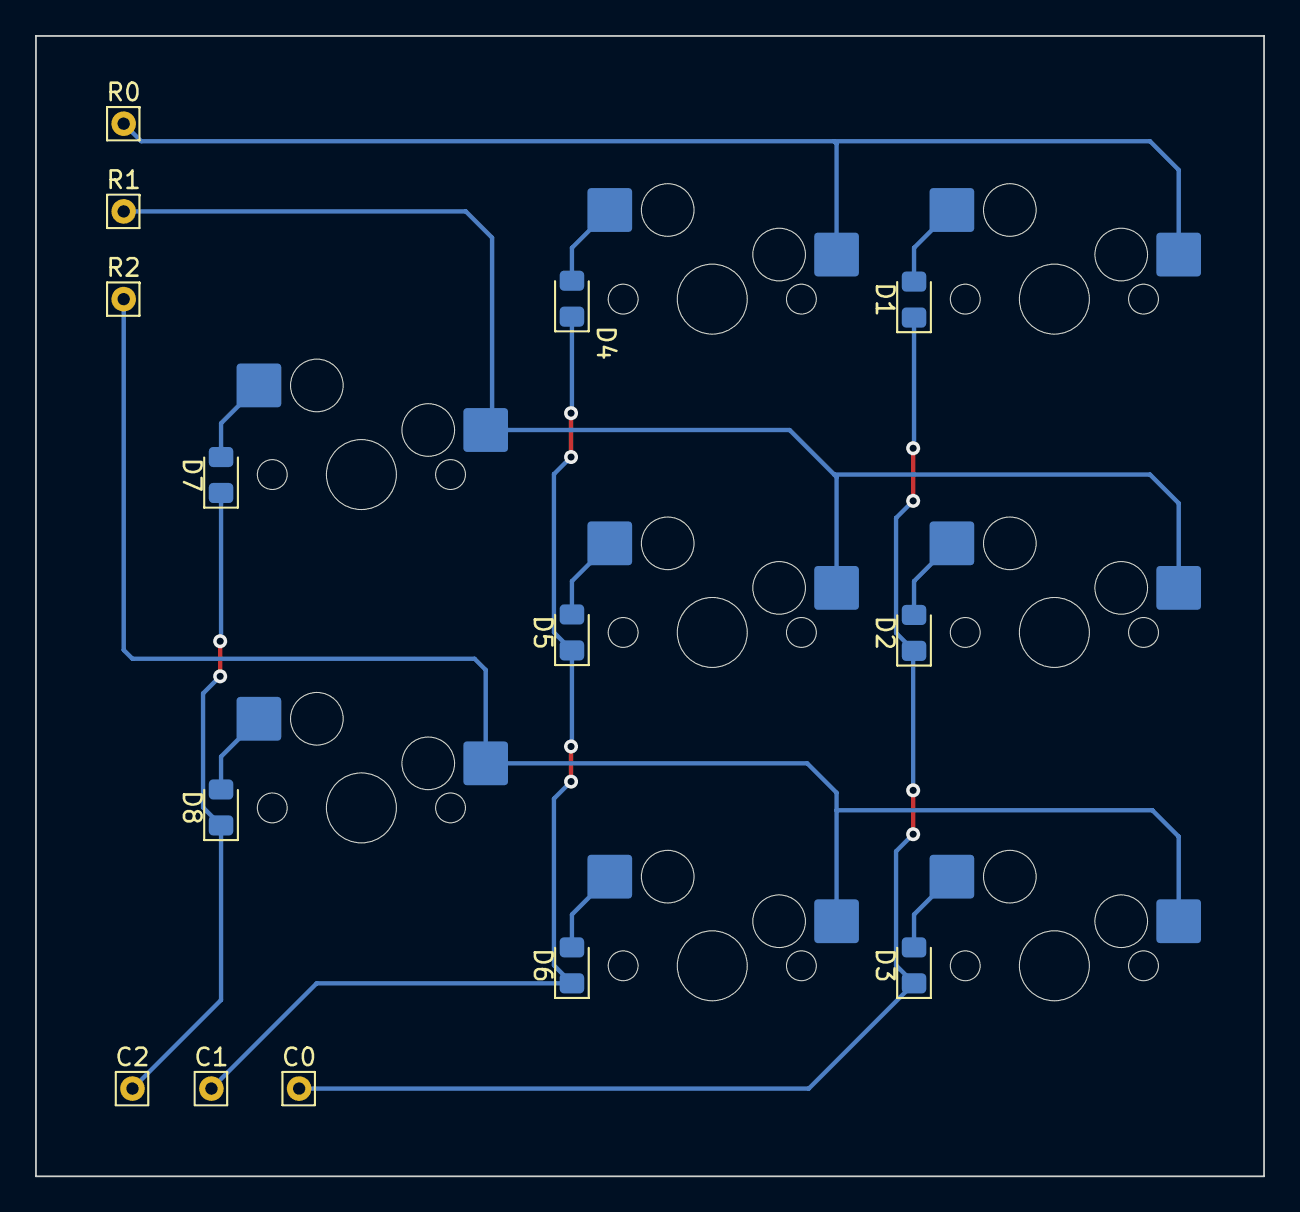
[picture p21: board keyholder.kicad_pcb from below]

Board: 2 copper layers, 70.0 x 65.0 mm, 22 parts (14 on the bottom side), 14 nets.

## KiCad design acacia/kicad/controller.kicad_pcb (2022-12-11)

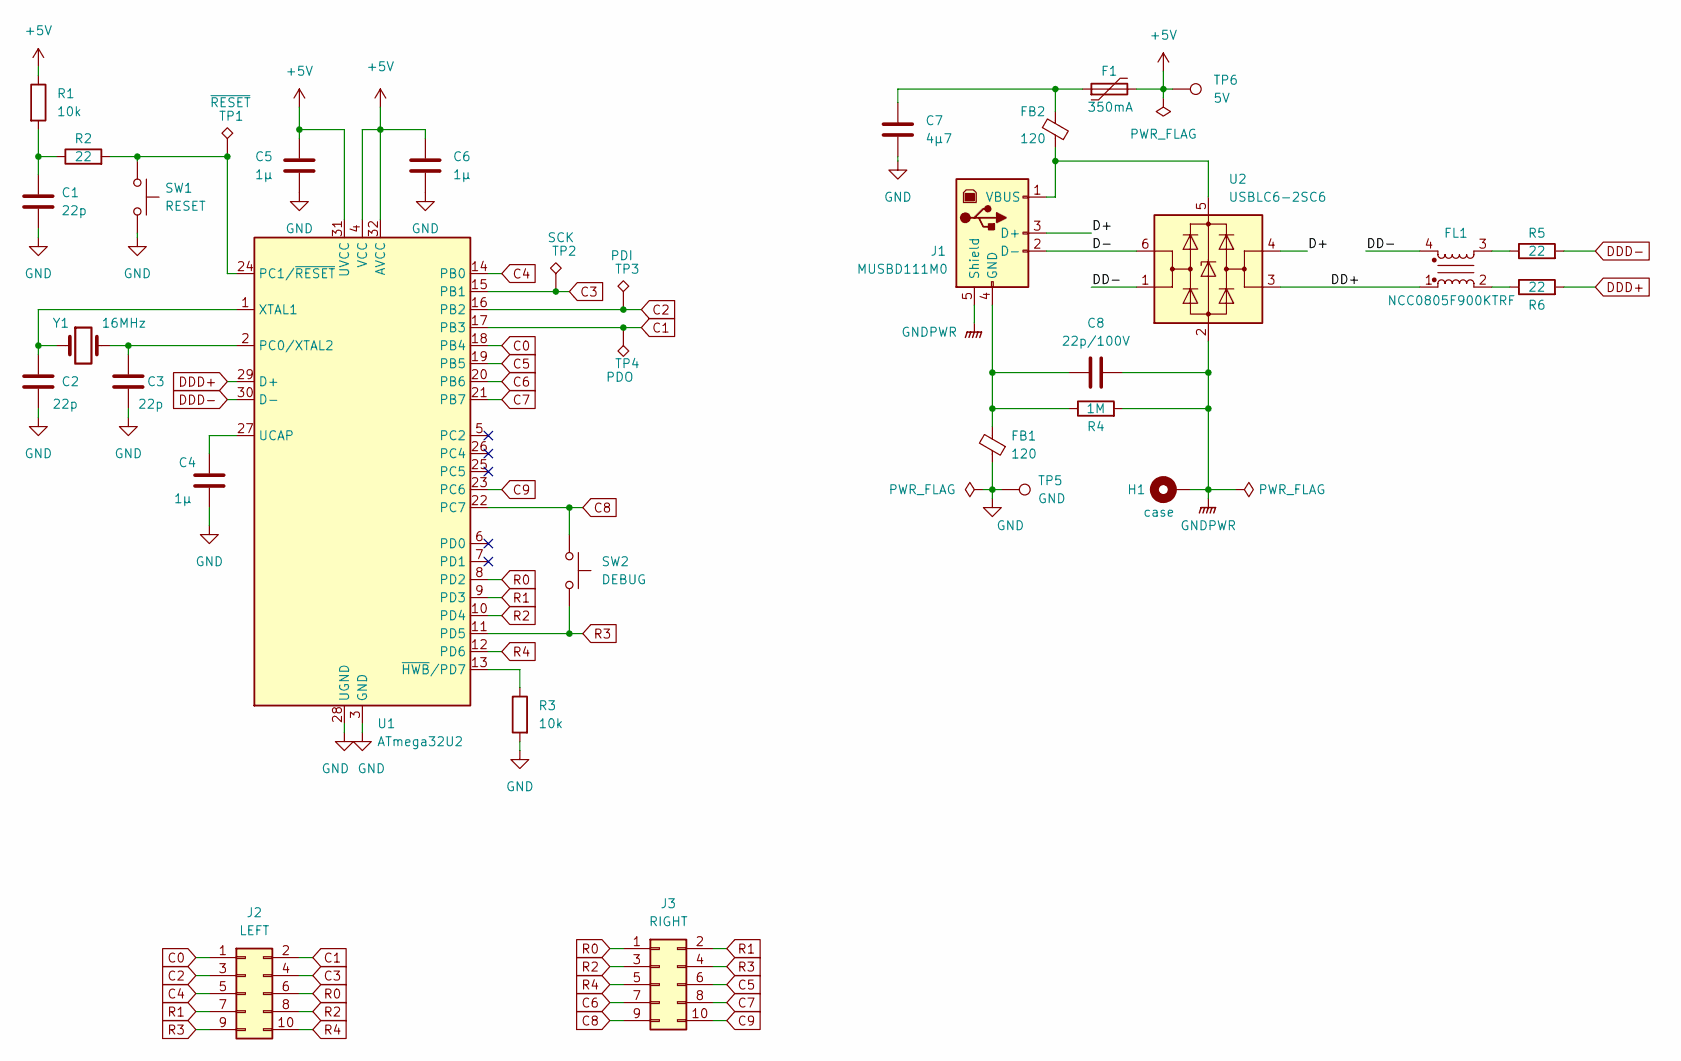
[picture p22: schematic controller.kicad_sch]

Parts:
C1, C2, C3: 22p; C_0805_2012Metric_Pad1.18x1.45mm_HandSolder
C4: 1µ; C_1206_3216Metric_Pad1.33x1.80mm_HandSolder
C5, C6: 1µ; C_0805_2012Metric_Pad1.18x1.45mm_HandSolder
C7: 4µ7; C_0805_2012Metric_Pad1.18x1.45mm_HandSolder
C8: 22p/100V; C_0805_2012Metric_Pad1.18x1.45mm_HandSolder
F1: 350mA; R_1210_3225Metric_Pad1.30x2.65mm_HandSolder
FB1, FB2: 120; R_0805_2012Metric_Pad1.20x1.40mm_HandSolder
FL1: NCC0805F900KTRF; L_CommonModeChoke_Coilcraft_0805USB
H1: case; MountingHole_3.2mm_M3_DIN965_Pad
J1: MUSBD111M0; AMPHENOL_MUSBD111M0
J2: LEFT; IDC-Header_2x05_P2.54mm_Horizontal
J3: RIGHT; IDC-Header_2x05_P2.54mm_Horizontal
R1, R3: 10k; R_0805_2012Metric_Pad1.20x1.40mm_HandSolder
R2, R5, R6: 22; R_0805_2012Metric_Pad1.20x1.40mm_HandSolder
R4: 1M; R_0805_2012Metric_Pad1.20x1.40mm_HandSolder
SW1: RESET; SW_SPST_EVQQ2
SW2: DEBUG; SW_SPST_EVQQ2
TP1: ~{RESET}; TestPoint_Pad_1.0x1.0mm
TP2: SCK; TestPoint_Pad_1.0x1.0mm
TP3: PDI; TestPoint_Pad_1.0x1.0mm
TP4: PDO; TestPoint_Pad_1.0x1.0mm
TP5: GND; TestPoint_Pad_1.0x1.0mm
TP6: 5V; TestPoint_Pad_1.0x1.0mm
U1: ATmega32U2; TQFP-32_7x7mm_P0.8mm
U2: USBLC6-2SC6; SOT-23-6
Y1: 16MHz; Crystal_SMD_HC49-SD

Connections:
+5V: C5.1, C6.1, F1.2, R1.1, TP6.1, U1.4 (VCC), U1.31 (UVCC), U1.32 (AVCC)
/D+: J1.3 (D+), U2.4 (I/O2)
/D-: J1.2 (D-), U2.6 (I/O1)
/DD+: FL1.1, U2.3 (I/O2)
/DD-: FL1.4, U2.1 (I/O1)
C0: J2.1, U1.18 (PB4)
C1: J2.2, TP4.1, U1.17 (PB3)
C2: J2.3, TP3.1, U1.16 (PB2)
C3: J2.4, TP2.1, U1.15 (PB1)
C4: J2.5, U1.14 (PB0)
C5: J3.6, U1.19 (PB5)
C6: J3.7, U1.20 (PB6)
C7: J3.8, U1.21 (PB7)
C8: J3.9, SW2.1, U1.22 (PC7)
C9: J3.10, U1.23 (PC6)
DDD+: R6.2, U1.29 (D+)
DDD-: R5.2, U1.30 (D-)
GND: C1.2, C2.2, C3.2, C4.2, C5.2, C6.2, C7.2, FB1.1, R3.2, SW1.2, TP5.1, U1.3 (GND), U1.28 (UGND)
GNDPWR: C8.1, H1.1, J1.5 (Shield), R4.2, U2.2 (GND)
unnamed: C1.1, R1.2, R2.1
unnamed: C2.1, U1.1 (XTAL1), Y1.1
unnamed: C3.1, U1.2 (PC0/XTAL2), Y1.2
unnamed: C4.1, U1.27 (UCAP)
unnamed: C7.1, F1.1, FB2.1
unnamed: C8.2, FB1.2, J1.4 (GND), R4.1
unnamed: FB2.2, J1.1 (VBUS), U2.5 (VBUS)
unnamed: FL1.2, R6.1
unnamed: FL1.3, R5.1
unnamed: R2.2, SW1.1, TP1.1, U1.24 (PC1/~RESET)
unnamed: R3.1, U1.13 (~HWB/PD7)
R0: J2.6, J3.1, U1.8 (PD2)
R1: J2.7, J3.2, U1.9 (PD3)
R2: J2.8, J3.3, U1.10 (PD4)
R3: J2.9, J3.4, SW2.2, U1.11 (PD5)
R4: J2.10, J3.5, U1.12 (PD6)

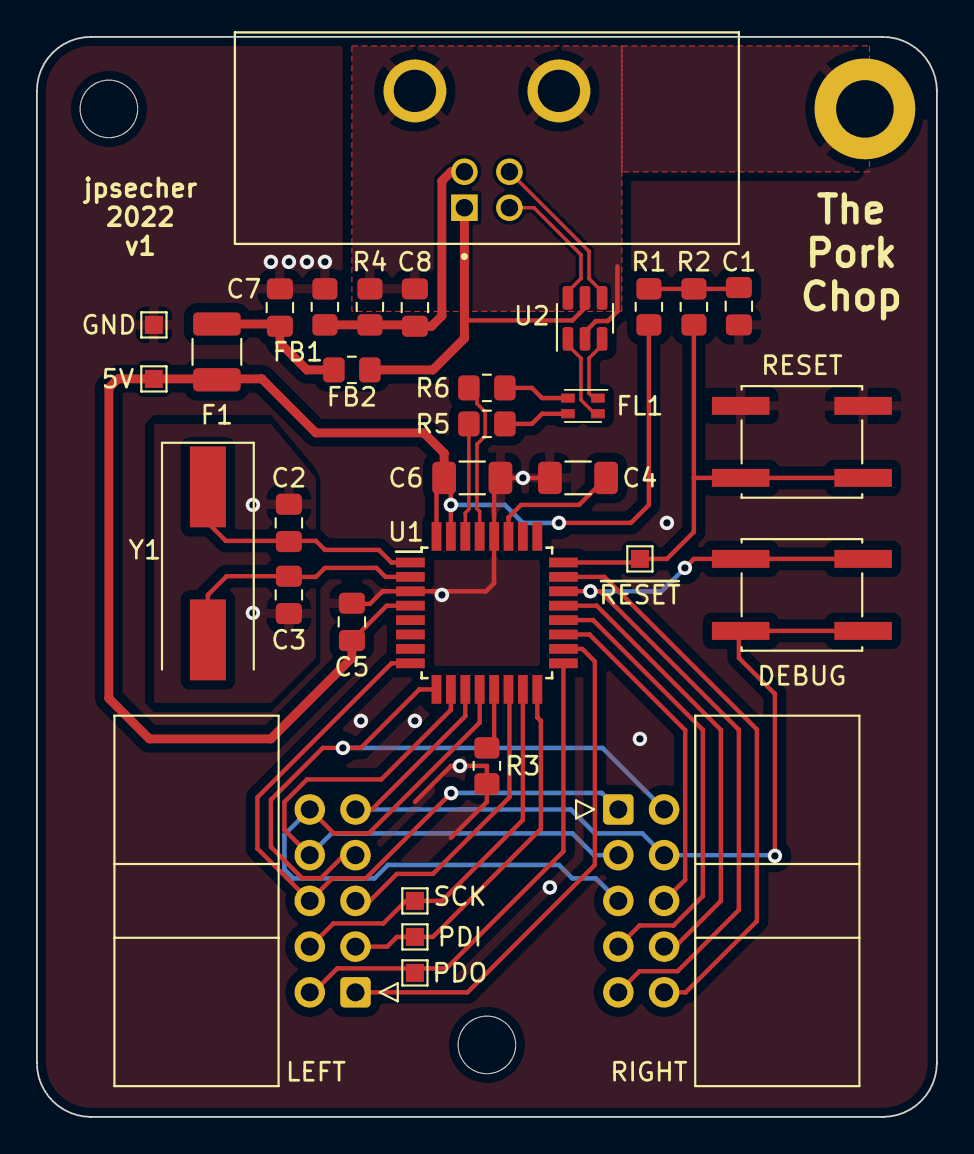
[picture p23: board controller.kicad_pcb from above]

Board: 2 copper layers, 50.0 x 60.0 mm, 33 parts (0 on the bottom side), 35 nets.

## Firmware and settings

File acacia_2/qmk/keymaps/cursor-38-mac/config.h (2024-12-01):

/*
Copyright 2024 Jens Peter Secher <jpsecher@gmail.com>

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
You should have received a copy of the GNU General Public License
along with this program.  If not, see <http://www.gnu.org/licenses/>.
*/

#pragma once

#define TAPPING_TERM 225
#define PERMISSIVE_HOLD
#define TAPPING_TOGGLE 2

// Cancel one-shot after one second
#define ONESHOT_TIMEOUT 1000

// Smart caps lock cancels after 10 seconds.
#define DOUBLE_TAP_SHIFT_TURNS_ON_CAPS_WORD
#define CAPS_WORD_IDLE_TIMEOUT 10000

#define WS2812_DI_PIN B5
#define RGBLED_NUM 6
#define RGBLIGHT_LAYERS
#define RGBLIGHT_LAYER_BLINK

#define POINTING_DEVICE_ROTATION_90

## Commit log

2022-11-12 Hidden config buttons
2022-11-14 Switch Tab/Enter
2022-11-14 WIP: schematic
    [the_tree.kicad_pcb, the_tree.kicad_sch]
2022-11-15 schematic and footprints from ai03
    [the_tree.kicad_sch]
2022-11-17 Schematic for full keyboard
    [the_tree.kicad_sch]
2022-11-17 Earth connection on the other side of filter
    [the_tree.kicad_sch]
2022-11-23 OpenSCAD plate
    [plate.scad]
2022-11-23 Slick contour
    [plate.scad]
2022-11-25 Top tabs
    [plate.scad]
2022-11-25 both sides
    [plate.scad]
2022-11-27 Bottom skirt
    [plate.scad]
2022-11-27 Updated spacing based on prototype
    [plate.scad]
2022-11-27 Better feet
    [plate.scad]
2022-11-29 40 keys
    [plate.scad, the_tree.kicad_sch]
2022-11-29 Complete board
    [plate.scad]
2022-12-03 Silk screen
    [case.scad, pork-chop-control.kicad_pcb, pork-chop-control.kicad_sch]
2022-12-03 cable hole
    [case.scad]
2022-12-04 move programming pads
    [pork-chop-control.kicad_pcb, pork-chop-control.kicad_sch]
2022-12-11 Newest layout
    [pork-chop-control-B_Cu.gbr, pork-chop-control-B_Mask.gbr, pork-chop-control-B_Paste.gbr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]
2022-12-13 thinner plate & room for connector
    [case.scad]
2022-12-13 use actual cap sizes
    [case.scad]
2022-12-13 generic key size
    [case.scad]
2022-12-13 2D projection for export to SVG
    [case.scad]
2022-12-14 better minus
    [case.scad]
2022-12-14 full board wip
    [pork-chop.kicad_pcb, pork-chop.kicad_sch]
2022-12-15 layout with 1.5u & 1.25u
    [case.scad]
2022-12-17 pcb with standoffs
    [case.scad]
2022-12-18 before reorder
    [case.scad, pork-chop.kicad_pcb, pork-chop.kicad_sch]
2022-12-19 keys layed out
    [acacia.kicad_pcb, acacia.kicad_sch, the_tree.kicad_pcb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]
2022-12-20 keys routed
    [acacia.kicad_pcb, acacia.kicad_sch]
2022-12-21 Layer swap & normal numbers
    [acacia.scad]
2022-12-21 routing done
    [acacia.kicad_pcb]
2022-12-23 pcb finished
    [acacia-B_Cu.gbr, acacia-B_Mask.gbr, acacia-B_Paste.gbr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]
2022-12-26 plate only
    [acacia.scad, acacia.stl]
2023-01-16 Small finger adjustment
2023-01-25 Switch deletion and shift
2023-01-26 Status LED
2023-04-06 Drop lower thumbs
    [acacia.scad, acacia.stl]
2023-04-07 Starting V2 layout
    [acacia-v2.scad]
2023-04-09 V2 PCB started
    [acacia-2.kicad_pcb, acacia-2.kicad_sch]
2023-04-10 WIP: v2 board
    [acacia-2.kicad_pcb, acacia-2.kicad_sch, acacia-v2.scad]
2023-04-27 Alpha layer on Esc
2023-04-29 New USB connector
    [acacia-2.kicad_pcb, acacia-2.kicad_sch]
2023-09-01 USB cutout only half
    [acacia-v2.scad]
2023-10-01 qwerty layout
    [acacia-2.kicad_sch]
2023-10-18 before reordering
    [acacia-2.kicad_pcb, acacia-2.kicad_sch]
2023-10-18 V2 gerber
    [acacia-2-B_Cu.gbr, acacia-2-B_Mask.gbr, acacia-2-B_Paste.gbr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]
2023-12-04 Swap Nav & AGr, clear Esc
2024-01-23 Adjust key position to better fit actual layout
    [acacia-2.kicad_pcb]
2024-01-28 Cut out for flat cable
    [acacia-v2.scad]
2024-01-29 mouse wheel
2024-03-28 BAV70U quad diode
2024-03-30 Switch round Esc/Tab & one-shot alpha in Navi
2024-07-24 Starting v3: Thrice
    [thrice.scad]
2024-09-14 testing delimiter together
    [acacia-2.kicad_sch]
2024-12-07 final choc cover cap
    [choc-v2-cover.scad, choc-v2-cover.stl]
2024-12-08 Choc v1 covers
    [choc-v1-cover.scad, choc-v1-cover.stl]

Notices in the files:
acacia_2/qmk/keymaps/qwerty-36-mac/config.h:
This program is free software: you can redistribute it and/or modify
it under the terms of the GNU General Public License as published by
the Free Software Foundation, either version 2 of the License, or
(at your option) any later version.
